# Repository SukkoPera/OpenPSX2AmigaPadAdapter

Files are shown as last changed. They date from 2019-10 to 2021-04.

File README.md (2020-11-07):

# OpenPSX2AmigaPadAdapter
OpenPSX2AmigaPadAdapter is an Open Hardware adapter that allows using a Sony PlayStation controller on Commodore computers, including the Commodore 64, Amiga and CD<sup>32</sup>.

Board

## Summary
The Commodore Amiga CD<sup>32</sup> came with cumbersome and fragile controllers, most of which did not survive the challenge of time. While many third-party replacements have surfaced in the meantime, most of them are not as solid and comfortable as the ubiquitous Sony PlayStation controllers. These have more than enough buttons, are cheap and most people are familiar with them, as the same basic design has been around for nearly 25 years. This means they would be a very good replacement, if they just didn't use a different connector and communication protocol.

OpenPSX2AmigaPadAdapter is a simple [Arduino](https://www.arduino.cc)-based board that adapts the connector and translates the protocol, allowing the use of many PlayStation controllers on Commodore computers. It can either behave as a simple 1/2-button Atari-style joystick or as a full-fledged 7-button CD<sup>32</sup> gamepad. It can also appear as an Amiga mouse.

## Operating Modes
The adapter has two leds:
- LD1 lights up steadily when a supported controller is plugged in. It blinks when no controller - or an unsupported one - is connected.
- LD2 indicates the current operating mode, to be interpreted as follows.

### Two-Button Joystick Mode
When the adapter is powered on, it defaults to Atari-style Two-Button Mode, which is indicated by LD2 being off.

This mode has been throughly tested on several Amiga models, but it **should** work wherever an Atari-style joystick is supported, including the Commodore VIC-20, Commodore 16 (through an [adapter](https://github.com/SukkoPera/OpenC16JoyAdapter)), Commodore 64, etc. See [below](#computers-and-consoles) for a compatibility table.

While in this mode, the adapter supports different button mappings, which have been carefully designed and tailored to different game genres. The mappings can be switched by pressing <kbd>Select</kbd> in combination with other buttons. LD2 will blink quickly a few times to indicate what mapping has been activated.

#### Standard Mapping: <kbd>Select</kbd> + <kbd>&square;</kbd>
Standard Mapping is the simplest mapping possible: both the D-Pad and Left Analog work as direction buttons. <kbd>&square;</kbd> is <kbd>B1</kbd> and <kbd>&cross;</kbd> is <kbd>B2</kbd>. This is the default mapping as it should be usable just about in every game out there. It might not be the most natural these days, but it's the way the game was meant to be played by the developers, thus it should never fail you.

Note that very few games were originally made to take advantage of two buttons, as even fewer controllers had that many (!) those days. [Here is a list](http://eab.abime.net/showthread.php?t=57540) of Amiga games that somehow support two buttons, if it can be any useful.

LD2 will blink once when this mapping is activated.

#### Racing Mapping 1: <kbd>Select</kbd> + <kbd>&triangle;</kbd>
Racing Mapping 1 is useful for all those racing games that use <kbd>&uarr;</kbd> to accelerate and <kbd>&darr;</kbd> to brake. These have been mapped to <kbd>&square;</kbd> and <kbd>&cross;</kbd>, respectively, which should make them much more natural to play. When accelerating and braking at the same time, braking wins. Left Analog can be used to steer, but its vertical axis is ignored, to avoid accidental accelerating/braking. The D-Pad is fully functional and is handy when moving through menus. <kbd>B1</kbd> and <kbd>B2</kbd> can be found on <kbd>&triangle;</kbd> and <kbd>&cir;</kbd>.

This mode is probably best suited to games that do not involve shifting gears, as downshifting is usually performed through <kbd>&darr;</kbd> + <kbd>B1</kbd> which is pretty hard to achieve (<kbd>&triangle;</kbd> + <kbd>&cross;</kbd>).

LD2 will blink twice when this mapping is activated.

#### Racing Mapping 2: <kbd>Select</kbd> + <kbd>&cir;</kbd>
Racing Mapping 2 is an alternative mapping for racing games that was inspired by GTA V. It lets you use <kbd>R2</kbd> (or <kbd>R1</kbd>) to accelerate and <kbd>L2</kbd> (or <kbd>L1</kbd>) to brake (which means they map to <kbd>&uarr;</kbd> and <kbd>&darr;</kbd>, respectively). <kbd>B1</kbd> is mapped to its natural <kbd>&square;</kbd> position. Steering and the D-Pad work as in Racing Mode 1.

Accidentally, this control scheme was found out to be very comfortable with games that use <kbd>B1</kbd> to accelerate and <kbd>&uarr;</kbd> and <kbd>&darr;</kbd> to shift gears. Since <kbd>&darr;</kbd> is probably used for braking as well, it has also been mapped to <kbd>&cross;</kbd>, while <kbd>B2</kbd> has been moved to <kbd>&triangle;</kbd>.

LD2 will blink three times when this mapping is activated.

#### Platform Mapping: <kbd>Select</kbd> + <kbd>&cross;</kbd>
Platform Mapping is very similar to Standard Mapping, it just makes jumping way easier on a joypad and more natural to all the Mario players out there, by replicating <kbd>&uarr;</kbd> on <kbd>&cross;</kbd>. Consequently, <kbd>B2</kbd> has been moved to <kbd>&triangle;</kbd>.

LD2 will blink four times when this mapping is activated.

#### Custom Mappings: <kbd>Select</kbd> + <kbd>R1</kbd>/<kbd>R2</kbd>/<kbd>L1</kbd>/<kbd>L2</kbd>
What if the built-in mappings are not enough? OpenPSX2AmigaPadAdapter allows you to make your own! And you can have up to four different ones, which are stored internally so that they can be recalled at any time. By default they behave similarly to the Standard Mapping, but they can be customized so that any button produces either the press of a single button or even of a button combo!

The programming procedure is as follows:

1. Press and hold <kbd>Select</kbd>, then press and hold one of <kbd>R1</kbd>/<kbd>R2</kbd>/<kbd>L1</kbd>/<kbd>L2</kbd> until LD2 starts blinking, finally release both buttons. You are now in Programming Mode.
2. Press the button you want to configure. LD2 will flash quickly a few times.
3. Press and hold the single button or button combo you want to be assigned to the button you pressed before. At this stage the D-Pad directions have their obvious meaning, while <kbd>&square;</kbd> represents <kbd>B1</kbd> and <kbd>&cross;</kbd> represents <kbd>B2</kbd>. LD2 will again flash quickly a few times.
4. Release the button or combo you were holding.
5. Repeat steps 2-4 for every button you want to customize.
6. When you are done, press <kbd>Select</kbd> to store the mapping and leave Programming Mode. LD2 will stop blinking and you will be back to Two-Button Joystick Mode.

Note that a mapping you have just programmed is not activated automatically, so you will have to press <kbd>Select</kbd> and one of <kbd>R1</kbd>/<kbd>R2</kbd>/<kbd>L1</kbd>/<kbd>L2</kbd> (and release them quickly) to switch to it.

The Custom Mappings **cannot** be configured so that <kbd>&darr;</kbd> overrides <kbd>&uarr;</kbd> or so that the vertical axis of Left Analog is ignored, still they might be useful here and there. For instance, having <kbd>B1</kbd> + <kbd>&uarr;</kbd> on <kbd>&cross;</kbd> and <kbd>B1</kbd> + <kbd>&darr;</kbd> on <kbd>&triangle;</kbd> makes the Amiga version of *Golden Axe* much more playable.

#### Commodore 64 Mode
Button 2 on Commodore 64 usually behaves in the opposite way at the electrical level, with respect to the other buttons. So a tweak can be enabled to invert the behaviour of button 2, use it if you find that your game of choice always sees it pressed or if it triggers on release rather than on press.

Just hold <kbd>Select</kbd> and press <kbd>Start</kbd> briefly. LD2 will flash once when this tweak is enabled and twice when it is disabled.

### Mouse Mode
Whenever the right analog stick is moved, the adapter switches to Amiga Mouse Mode. In this mode, the right stick emulates the movements of a mouse. Movement speed is somewhat proportional to how far the stick is moved.

This mode can be useful as an emergency mouse, and it will be particularly handy if you have the adapter connected to port 1 of an Amiga computer and you need to use a mouse for short while (maybe to do some settings in a cracktro). Instead of unplugging the adapter, plugging in a mouse, and then the adapter again, you can take advantage of this feature.

Mouse mode is indicated by LD2 blinking. Press any direction on the D-Pad to go back to Joystick or CD32 Mode.

### CD<sup>32</sup> Controller Mode
When the adapter is connected to a CD<sup>32</sup> console, it will automatically switch into this mode, which will emulate all 7 buttons of the original CD<sup>32</sup> controller. LD2 will light up steadily.

By default, buttons are mapped as follows:
- <kbd>&square;</kbd>: Red
- <kbd>&cross;</kbd>: Blue
- <kbd>&cir;</kbd>: Yellow
- <kbd>&triangle;</kbd>: Green
- <kbd>L1</kbd>/<kbd>L2</kbd>/<kbd>L3</kbd>: L
- <kbd>R1</kbd>/<kbd>R2</kbd>/<kbd>R3</kbd>: R
- <kbd>Start</kbd>: Start/Pause

If you press <kbd>Select</kbd>, the 4 main buttons get "rotated":
- <kbd>&cross;</kbd>: Red
- <kbd>&cir;</kbd>: Blue
- <kbd>&triangle;</kbd>: Yellow
- <kbd>&square;</kbd>: Green

Both the D-Pad and Left Analog always work as direction buttons.

## Components and Assembly
The board is basically a customized Arduino Uno, this means it was designed to work with an ATmega328P microcontroller, but you can also use ATmega88/A/P/PA or ATmega168/P microcontrollers, as they are pin-compatible and slightly cheaper. The A/P/PA suffixes usually identify somewhat minor chip revisions, the board should work with all of them. If you can, use P or PA versions, which consume less power. Note that at the moment the firmware uses 99% of the flash space available on an ATmega88 and any possible future improvements and/or new features are likely to overflow that, so you'd better use an ATmega168 at least.

A noteworthy exception to this rule is the ATmega328P**B**, which is NOT 100% pin-compatible with the 328P. Nevertheless, it MIGHT just work as well. It might also destroy whatever you connect the adapter to, so do it **at your own risk**.

You are recommended to solder the microcontroller first. The TQFP-32 package is easier to solder than it looks, watch some videos on YouTube and develop your own technique. Just make sure to orient it correctly.

Solder the oscillator then. You can either use a through-hole crystal with its caps (these will depend on the crystal, but usually 18-22pF are a good bet) or a 3-pin resonator. Whichever you choose, it shall have a frequency of 16 MHz. If you choose the crystal, you might want to put some insulation tape under it to avoid it touching the pads for the resonator.

Solder all the remaining parts in the order you prefer, just keep the controller connectors last.

Note that the PlayStation controller is powered at 3.3V and the interface signals use the same voltage. Due to the particular circuit used for level shifting (the microcontroller works at 5V), the MOSFETs [should really be BSS138](https://electronics.stackexchange.com/questions/367052/replace-bss138-with-ao3400a-in-level-shifter-circuit).

The PlayStation controller connector can be found from many Chinese sellers as a spare part. Get one with 90° pins, otherwise the adapter will be pretty awkward to use. The pins will be pretty short, but you should manage to solder it in place. Make sure it sits level on the board, otherwise it might not fit in the [3D-printable case](#enclosure), which you are recommended to use in order to make the adapter more mechanically solid. In alternative, some hot glue behind the connector (where the pins are) seems to do the same job, but it won't look as pretty.

**Hint:** If you don't have the PCB, you can build a full adapter with an Arduino Uno/Nano/Whatever board. This is not supported though, so you are on your own, but all the information you need is in the schematics or in the firmware code :).

## Firmware
Before you can use the adapter, you will need to load some firmware (i.e.: an Arduino sketch) on it. This can be found under the [firmware](https://github.com/SukkoPera/OpenPSX2AmigaPadAdapter/tree/master/firmware) directory, along with instructions.

## Compatibility
### Computers and Consoles
|System |Compatible |Notes |
|---|---|---|
|Commodore Amiga (All models) |Yes |Tested on A500+ and A1200 (1.D3), it is expected to be compatible with all models in both 2- and 7-button Joystick modes and in Mouse mode. |
|Commodore Amiga CD<sup>32</sup>  |Yes |Both 2- and 7-button Joystick modes and Mouse mode. Games not using `lowlevel.library` might be a bit of hit-and-miss, please report any misbehaviours. |
|Commodore CDTV |Maybe|**Not tested yet**, but expected to work in 2-button Joystick mode and Mouse mode through a connector adapter. |
|Commodore 64 |Yes |Tested in 2-button Joystick mode, but second button untested. Mouse mode might damage CIA chips though, be careful not to turn it on! |
|Commodore 16 |Maybe|**Not tested yet**, but expected to work in 2-button Joystick mode through [OpenC16JoyAdapter](https://github.com/SukkoPera/OpenC16JoyAdapter). C16 only supports Button 1 though. |
|Commodore VIC-20 |Maybe|**Not tested yet**, but expected to work in 2-button Joystick mode. Be careful with Mouse mode. |
|Sega Master System |No |Would probably work in 2-button Joystick mode if power was routed from pin 5 on the SMS controller port to pin 7 of the adapter. |
|Sega Mega Drive/Genesis |No |Would probably work as an SMS controller with the same mod as above. Some more pin rerouting AND a custom firmware could make it appear as a Mega Drive 6-button controller. |
|MSX |No |Would probably work in 2-button Joystick mode by swapping a few pins on the controller port. |

### Controllers
The latest versions of the OpenPSX2AmigaPadAdapter firmware use [PsxNewLib](https://github.com/SukkoPera/PsxNewLib) to read the PlayStation controller. This makes it compatible with (almost) all controllers.

Please refer to the [PsxNewLib Compatibility List](https://github.com/SukkoPera/PsxNewLib#compatibility-list) for details.

## Current Consumption
Following are the results of some rough measurements:
- An ATmega88PA-based OpenPSX2AmigaPadAdapter with an original Sony Dual Shock/Dual Shock 2 controller connected draws about 20 mA.
- Consumption rises to 25 mA with the dongle of my EastVita wireless controller, when the controller is connected. It peaks to 35 mA while it is searching for the controller.
- Using an ATmega328P bumps all consumptions by 5 mA.

This means that the current absorbed by the adapter is "reasonable" and that it should be safe to use in all cases. It is well below the 100 mA maximum available from any Amiga controller ports, for instance.

## Enclosure
Three different 3D-printable enclosures are currently available for this board:
- The [first](https://github.com/SukkoPera/OpenPSX2AmigaPadAdapter/tree/master/enclosure) one was kindly contributed by Petros Kokotis and needs screws for assembly.
- A [second one](https://www.thingiverse.com/thing:4620027) was designed by Lemaru and uses a snap-in design. It also has holes for the LEDs.
- [Another one](https://github.com/SukkoPera/OpenPSX2AmigaPadAdapter/tree/master/enclosure/cd32) was made by Gary Ogden and is better suited for use with the CD<sup>32</sup>, as it has some kind of bottom support.

My gratitude goes to all the three guys for their great work and support!

### Releases
If you want to get this board produced, you are recommended to get [the latest release](https://github.com/SukkoPera/OpenPSX2AmigaPadAdapter/releases) rather than the current git version, as the latter might be under development and is not guaranteed to be working.

Every release is accompanied by its Bill Of Materials (BOM) file and any relevant notes about it, which you are recommended to read carefully.

## License
The OpenPSX2AmigaPadAdapter documentation, including the design itself, is copyright &copy; SukkoPera 2019-2020.

OpenPSX2AmigaPadAdapter is Open Hardware licensed under the [CERN OHL v. 1.2](http://ohwr.org/cernohl).

You may redistribute and modify this documentation under the terms of the CERN OHL v.1.2. This documentation is distributed *as is* and WITHOUT ANY EXPRESS OR IMPLIED WARRANTIES whatsoever with respect to its functionality, operability or use, including, without limitation, any implied warranties OF MERCHANTABILITY, SATISFACTORY QUALITY, FITNESS FOR A PARTICULAR PURPOSE or infringement. We expressly disclaim any liability whatsoever for any direct, indirect, consequential, incidental or special damages, including, without limitation, lost revenues, lost profits, losses resulting from business interruption or loss of data, regardless of the form of action or legal theory under which the liability may be asserted, even if advised of the possibility or likelihood of such damages.

A copy of the full license is included in file [LICENSE.pdf](LICENSE.pdf), please refer to it for applicable conditions. In order to properly deal with its terms, please see file [LICENSE_HOWTO.pdf](LICENSE_HOWTO.pdf).

The contact points for information about manufactured Products (see section 4.2) are listed in file [PRODUCT.md](PRODUCT.md).

Any modifications made by Licensees (see section 3.4.b) shall be recorded in file [CHANGES.md](CHANGES.md).

The Documentation Location of the original project is https://github.com/SukkoPera/OpenPSX2AmigaPadAdapter/.

## Support the Project
Since the project is open you are free to get the PCBs made by your preferred manufacturer, however in case you want to support the development, you can order them from PCBWay through this link:

PCB from PCBWay (https://www.pcbway.com/project/shareproject/OpenPSX2AmigaPadAdapter_V3.html)

You get my gratitude and cheap, professionally-made and good quality PCBs, I get some credit that will help with this and [other projects](https://www.pcbway.com/project/member/shareproject/?bmbid=41100). You won't even have to worry about the various PCB options, it's all pre-configured for you!

Also, if you still have to register to that site, [you can use this link](https://www.pcbway.com/setinvite.aspx?inviteid=41100) to get some bonus initial credit (and yield me some more).

Again, if you want to use another manufacturer, feel free to, don't feel obligated :). But then you can buy me a coffee if you want:

<a href='https://ko-fi.com/L3L0U18L' target='_blank'>Buy Me a Coffee at ko-fi.com</a>

### Get Help
If you need help or have questions, you can join [the official Telegram group](https://t.me/joinchat/HUHdWBC9J9JnYIrvTYfZmg).

### Thanks
- Gerd Kautzmann for information about the [CD32 controller protocol](http://gerdkautzmann.de/cd32gamepad/cd32gamepad.html)
- CuriousInventor for informtation about the [PlayStation controller protocol](http://store.curiousinventor.com/guides/PS2)
- majinga/screwbreaker for testing and bugfixes
- Petros Kokotis, Lemaru and Gary Ogden for the 3D-printable enclosures
- Sarang Dumbre for the [3D model of the PlayStation connector](https://grabcad.com/library/ps-connector-female-1)

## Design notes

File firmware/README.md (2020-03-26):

# OpenPSX2AmigaPadAdapter Firmware

This is the firmware for the OpenPSX2AmigaPadAdapter project.

It it based on the [Arduino](https://www.arduino.cc) platform, since the OpenPSX2AmigaPadAdapter PCB is basically a customized *Arduino Uno* board. Hence you will need [the Arduino software](https://www.arduino.cc/en/Main/Software) to build and flash it to the board, so download and install it. Version 1.8.12 is the latest at the time of writing, and is recommended, although any later version should work as well.

## Core
The OpenPSX2AmigaPadAdapter firmware was tested using the default Arduino core on ATmega328P microcontrollers. You can also use ATmega88/A/P/PA or ATmega168/P microcontrollers (or even ATmega328P**B** at your risk), they are pin-compatible and slightly cheaper: in this case you will need [MiniCore](https://github.com/MCUdude/MiniCore).

## Libraries
You will need to install the following libraries:
- [PsxNewLib](https://github.com/SukkoPera/PsxNewLib): This library is used to read the PlayStation controller, you can also install it from the *Library Manager*, version 0.2.0 or later is required.
- [DigitalIO](https://github.com/SukkoPera/DigitalIO): You need this fork if your board has an ATmega88/A/P/PA or 328P**B** microcontroller, otherwise you can also use [the original version](https://github.com/greiman/DigitalIO).

If you need to install a library manually, just download the ZIP files and unpack them under ```libraries``` into your sketches directory. Please refer to the [Arduino documentation](https://www.arduino.cc/en/Guide/Libraries#toc5) for more information.

## Bootloader
You can either use a bootloader or not. There's not much difference from the functional point of view, as you will need some specialized hardware anyway:
- If you don't want to use a bootloader, you will need an AVR I(C)SP programmer every time you want to update the firmware. There are cheap clones everywhere, just look for *usbasp* or *tinyisp*.
- If you want to use a bootloader, you will still need an AVR programmer to flash the bootloader (and set the fuses) the first time, unless someone else does it for you. From then on you can just use a USB to Serial adapter. These are cheap too, just search for them. Not that useful unless you want to do some development/debugging, anyway.
- If you want to help with the debugging, you will need the USB to Serial adapter, so the only bonus in using a bootloader is that you can debug and reflash using it alone.
- Note that you can use an Arduino Uno (or similar) board as an AVR ISP programmer, if you already have one: follow [these instructions](https://www.arduino.cc/en/Tutorial/ArduinoISP).

If you go for the bootloader, you can either use the stock Arduino/MiniCore ones or have a look at the [bootloaders](https://github.com/SukkoPera/OpenPSX2AmigaPadAdapter/tree/master/firmware/bootloaders) directory, where you will find some versions of Optiboot that have been customized to flash LD2 when they startup (since there is no led connected to pin 13 as on most Arduino boards). Each of them is accompanied by the command line it was built with and by an ```avrdude``` command that can be used to flash it to the board without using the Arduino software.

## Fuses
Even if you don't want to use a bootloader, **you will need to burn it once in order to set some fuses** that are internal to the microcontroller to the right values. Then, if you don't want to use a bootloader, just pretend it never happened.

This is necessary because the Arduino software has no option dedicated to setting the fuses, but only does so contextually with burning the bootloader. In alternative, the ```bootloaders``` directory contains commands to set the fuses without using the Arduino software.

### ATmega328/P
Make sure that *Board* is set to *Arduino/Genuino Uno* under the *Tools* menu and select *Burn Bootloader*.

Note that this will set the fuses so that the board actually expects a bootloader to be installed, but programs seem to run correctly anyway if you flash them later through a programmer. You will lose 256 bytes of flash but it won't be a problem in this case, since this firmware is much smaller. To fix this properly you will need to set the fuses manually and use value ```0xDF``` for the High fuse.

### Atmega88/A/P/PA or ATmega328PB
Select the correct microcontroller type under *Tools* -> *Board* and *Variant* and set the other options in the same menu to the following values:
- Clock: *16 MHz external*
- BOD: *2.7V*
- Bootloader: *Yes* or *No* at your choice (Use the *UART0* option if applicable)

Finally select *Burn Bootloader*.

## Compiling and Flashing
1. Open the Arduino software
2. From the *File* menu select *Open* and browse to the ```OpenPSX2AmigaPadAdapter``` directory.
3. Select the correct *Board* and *Variant* under the *Tools* menu.
4. If using MiniCore, set the following values under the *Tools* menu:
   - Clock: *16 MHz external*
   - Compiler LTO: *Enabled*
5. If using the bootloader, connect the board through a Serial to USB adapter (It shall connect to the *FTDI* header on the board), make sure the correct serial port is selected in the *Tools* menu, then click on the *Upload* button (Second from left).
6. Otherwise, connect the board through an AVR programmer (using the the *ICSP* header on the board) and use the *Upload Using Programmer* menu option (Or hold <kbd>Shift</kbd> and click on the *Upload* button).

## Pin Mapping
Pins of the DB-9 connector are connected as follows on the OpenPSX2AmigaPadAdapter PCB:

|Pin#|Joystick  |CD32 |Mouse |Arduino Pin#|Arduino Pin Mode (Joystick Mode)|Arduino Pin Mode (CD32 Mode)|Arduino Pin Mode (Mouse Mode)|
|----|---|---|---|---|---|---|---|
|1 |Up |Up |V-pulse |4 |INPUT (HIGH)/OUTPUT (LOW) |INPUT (HIGH)/OUTPUT (LOW) |OUTPUT |
|2 |Down |Down |H-pulse |5 |INPUT (HIGH)/OUTPUT (LOW) |INPUT (HIGH)/OUTPUT (LOW) |OUTPUT |
|3 |Left |Left |VQ-pulse |6 |INPUT (HIGH)/OUTPUT (LOW) |INPUT (HIGH)/OUTPUT (LOW) |OUTPUT |
|4 |Right |Right |HQ-pulse |7 |INPUT (HIGH)/OUTPUT (LOW) |INPUT (HIGH)/OUTPUT (LOW) |OUTPUT |
|5 |(Button 3)|Load/Shift |MMB |2 (INT0) |INPUT |INPUT |INPUT |
|6 |Button 1  |SR Clock |LMB |3 (INT1) |INPUT (HIGH)/OUTPUT (LOW) |INPUT |INPUT (HIGH)/OUTPUT (LOW) |
|7 |+5V |+5V |+5V |- |- |- |- |
|8 |GND |GND |GND |- |- |- |- |
|9 |Button 2  |SR Output  |RMB |8 |INPUT (HIGH)/OUTPUT (LOW) |OUTPUT |INPUT (HIGH)/OUTPUT (LOW) |

Notes:
- All signals are active-low.
- Direction signals are actually driven in an open-collector fashion, which means they are toggled between INPUT (to make them HIGH) and OUTPUT mode (to make them LOW).
- This way of working requires external pull-up resistors: Those for the direction pins are built-in into the computer, while those for the buttons are on the board.

## AVR I/O Control
This is just for reference, don't care about it if you don't know what it means:

|DDR \ PORT| L | H |
|---|---|---|
| L | INPUT (5V) | INPUT + PULL-UP (5V)|
| H | OUTPUT LOW (0V)| OUTPUT HIGH (5V) |

## Logic Analyzer Plugin
The [LogicAnalyzer](https://github.com/SukkoPera/OpenPSX2AmigaPadAdapter/tree/master/firmware/LogicAnalyzer) directory contains a plug-in for the [Saleae Logic](https://www.saleae.com/downloads/) software that is capable of decoding the CD<sup>32</sup> controller protocol. It is not perfect but it's usable.

Please refer to the [Saleae documentation](https://github.com/saleae/SampleAnalyzer/tree/master/docs) for information on how to build the analyzer. Note that the directory contains a submodule, be sure to check it out as well.

## Releases
Stable versions of the firmware are released as part of the whole OpenPSX2AmigaPadAdapter project. You are recommended to use the firmware accompanying the hardware version you are using, but be sure to check [the latest release](https://github.com/SukkoPera/OpenPSX2AmigaPadAdapter/releases) as I'll try to maintain backwards compatibility. The current git version is NOT recommended though, as it might be under development and is not guaranteed to be working.

Every release is accompanied by any relevant notes about it, which you are recommended to read carefully.

## License
The OpenPSX2AmigaPadAdapter firmware is Copyright &copy; 2019-2020 by SukkoPera.

This program is free software: you can redistribute it and/or modify it under the terms of the GNU General Public License as published by the Free Software Foundation, either version 3 of the License, or (at your option) any later version.

This program is distributed in the hope that it will be useful, but WITHOUT ANY WARRANTY; without even the implied warranty of MERCHANTABILITY or FITNESS FOR A PARTICULAR PURPOSE.  See the GNU General Public License for more details.

You should have received a copy of the GNU General Public License along with this program. If not, see <http://www.gnu.org/licenses/>.

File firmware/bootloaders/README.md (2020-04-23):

# OpenPSX2AmigaPadAdapter Bootloaders
Here are some [Optiboot](https://github.com/Optiboot/optiboot) binaries customized for the OpenPSX2AmigaPadAdapter PCB.

They are compiled from the unmodified sources, the only difference versus the binaries included with Arduino and MiniCore are the LED pin, which is C1 on the OpenPSX2AmigaPadAdapter PCB.

For the commands below to work, you will need to add the AVR-GCC binaries directory to the PATH, i.e.:
```
export PATH=$PATH:/opt/arduino-1.8.10/hardware/tools/avr/bin
```

Note that your path might be different from the above. ```locate avrdude``` might help you find the correct directory.

## Flashing
You can flash these binaries with the Arduino software or simply with the ```avrdude``` tool as follows:

### ATmega328/P
#### Fuses
```
avrdude -C$HOME/.arduino15/packages/arduino/tools/avrdude/6.3.0-arduino14/etc/avrdude.conf -v -patmega328p -cusbasp -Pusb -e -Ulock:w:0x3F:m -Uefuse:w:0xFD:m -Uhfuse:w:0xDE:m -Ulfuse:w:0xFF:m
```

#### Bootloader Build
```
make atmega328 LED=C1
```

#### Bootloader Flash
```
avrdude -C$HOME/.arduino15/packages/arduino/tools/avrdude/6.3.0-arduino14/etc/avrdude.conf -v -patmega328p -cusbasp -Pusb -Uflash:w:optiboot_atmega328.hex:i -Ulock:w:0x0f:m
```

### ATmega328PB (Untested + TBD)
#### Fuses
```
avrdude -C$HOME/.arduino15/packages/arduino/tools/avrdude/6.3.0-arduino14/etc/avrdude.conf -v -patmega328pb -cusbasp -Pusb -e -Ulock:w:0x3f:m -Uefuse:w:0b11110101:m -Uhfuse:w:0xd6:m -Ulfuse:w:0b11111111:m 
```

#### Bootloader Build
```
make atmega328pb LED=C1 UART=0 BAUD_RATE=115200 AVR_FREQ=16000000
```

#### Bootloader Flash
```
avrdude -C$HOME/.arduino15/packages/arduino/tools/avrdude/6.3.0-arduino14/etc/avrdude.conf -v -patmega328pb -cusbasp -Pusb -Uflash:w:optiboot_atmega328pb_UART0_115200_16000000.hex:i -Ulock:w:0x0f:m
```

### ATmega88/A:
#### Fuses
```
avrdude -C$HOME/.arduino15/packages/MiniCore/hardware/avr/2.0.3/avrdude.conf -v -patmega88 -cusbasp -Pusb -e -Ulock:w:0x3f:m -Uefuse:w:0xfc:m -Uhfuse:w:0xd7:m -Ulfuse:w:0b11110111:m
```

#### Bootloader Build:
```
make atmega88 LED=C1 BAUD_RATE=115200 AVR_FREQ=16000000
```

#### Bootloader Flash
```
avrdude -C$HOME/.arduino15/packages/MiniCore/hardware/avr/2.0.3/avrdude.conf -v -patmega88 -cusbasp -Pusb -Uflash:w:optiboot_atmega88.hex:i -Ulock:w:0x0f:m
```

#### Application
```
avrdude -C$HOME/.arduino15/packages/MiniCore/hardware/avr/2.0.3/avrdude.conf -v -V -patmega88 -carduino -P/dev/ttyUSB0 -b115200 -D -Uflash:w:OpenPSX2AmigaPadAdapter.ino.hex:i 
```

### ATmega88P/A:
#### Fuses
```
avrdude -C$HOME/.arduino15/packages/MiniCore/hardware/avr/2.0.3/avrdude.conf -v -patmega88p -cusbasp -Pusb -e -Ulock:w:0x3f:m -Uefuse:w:0xfc:m -Uhfuse:w:0xd7:m -Ulfuse:w:0b11110111:m
```

#### Bootloader Build:
```
make atmega88pa LED=C1 UART=0 BAUD_RATE=115200 AVR_FREQ=16000000
```

#### Bootloader Flash
```
avrdude -C$HOME/.arduino15/packages/MiniCore/hardware/avr/2.0.3/avrdude.conf -v -patmega88p -cusbasp -Pusb -Uflash:w:optiboot_atmega88p_UART0_115200_16000000.hex:i -Ulock:w:0x0f:m
```

#### Application
```
avrdude -C$HOME/.arduino15/packages/MiniCore/hardware/avr/2.0.3/avrdude.conf -v -V -patmega88p -carduino -P/dev/ttyUSB0 -b115200 -D -Uflash:w:OpenPSX2AmigaPadAdapter.ino.hex:i 
```

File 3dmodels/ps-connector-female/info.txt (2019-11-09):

By sarang dumbre
https://grabcad.com/library/ps-connector-female-1
License is unknown

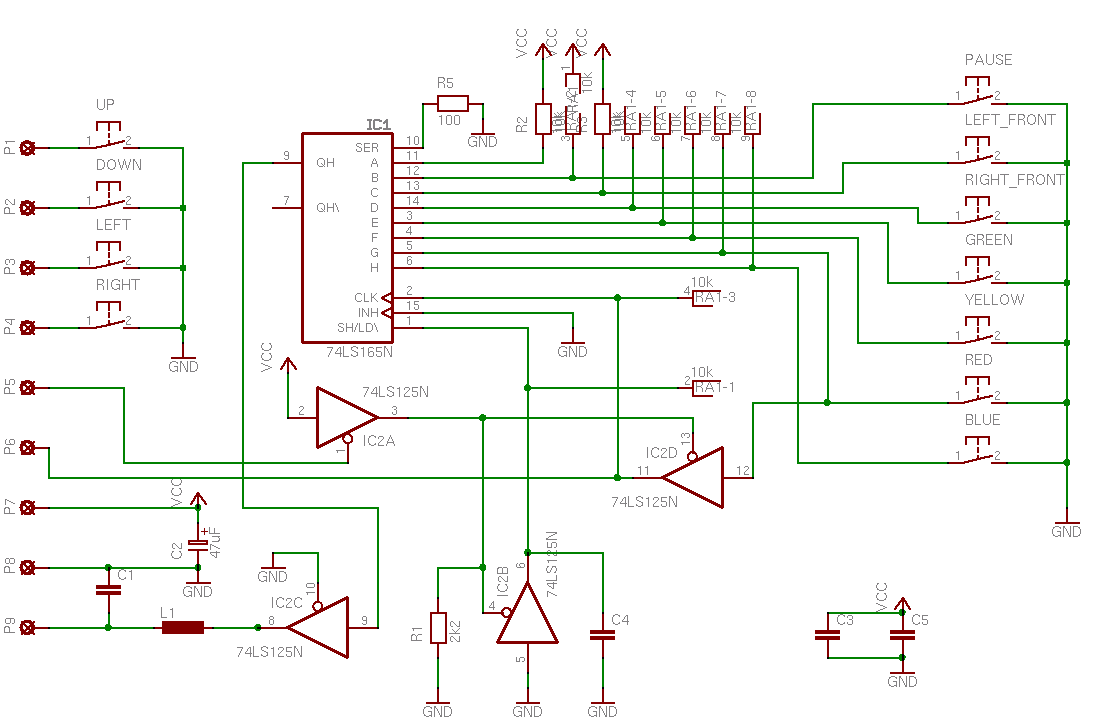
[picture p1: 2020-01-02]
doc/a100schematic.png

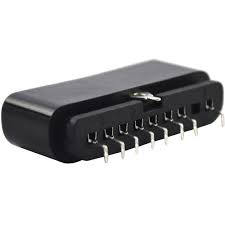
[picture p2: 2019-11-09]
3dmodels/ps-connector-female/download.jpg

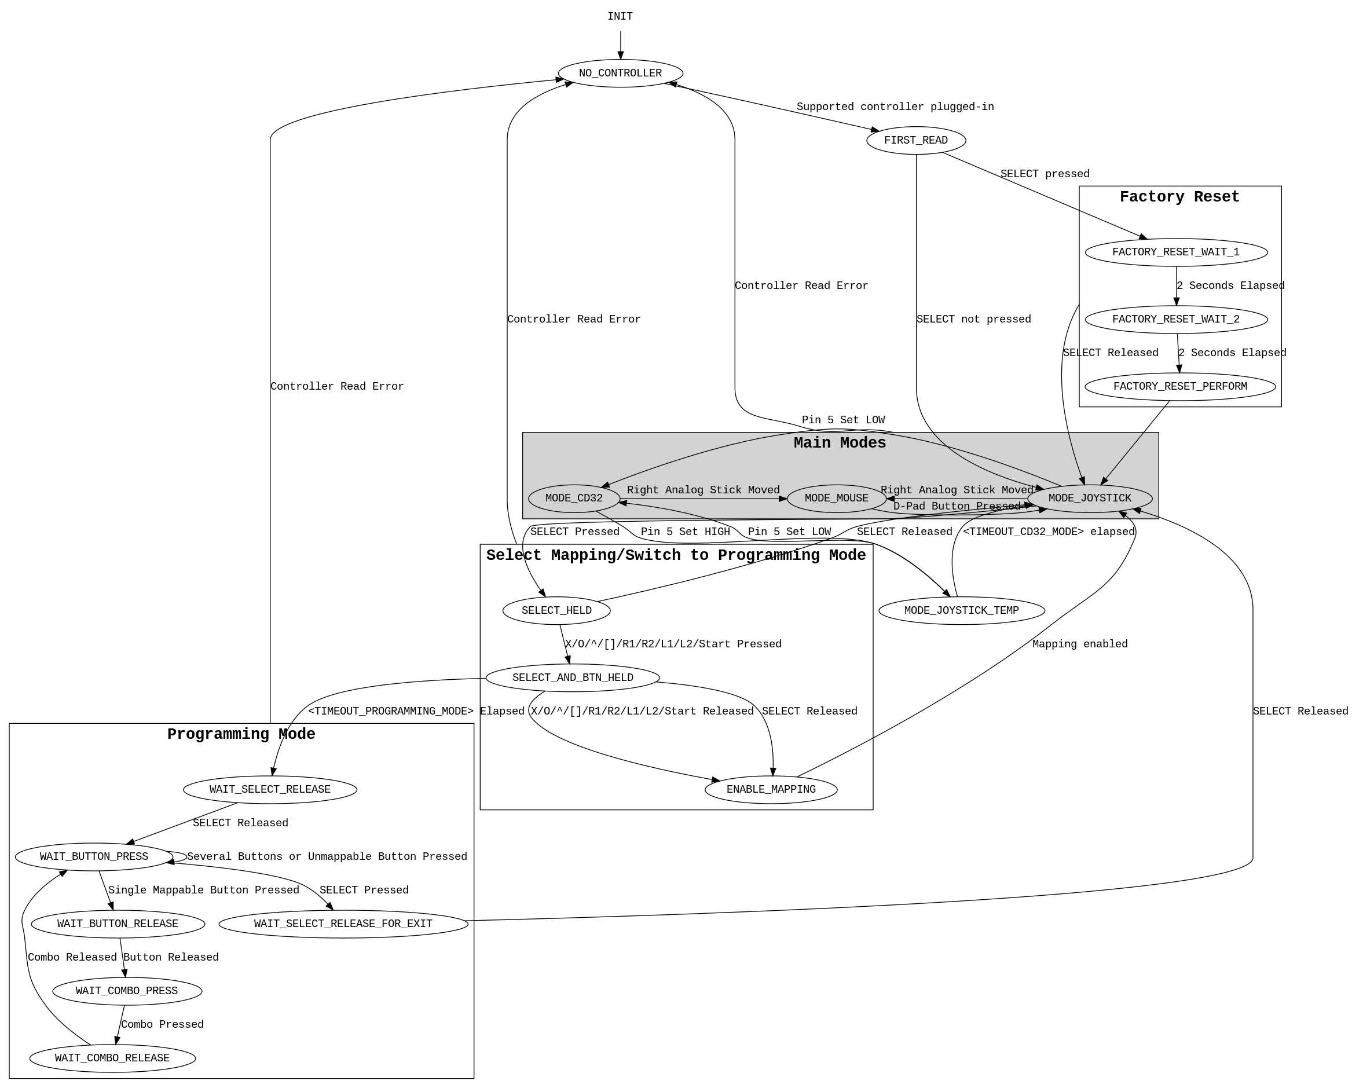
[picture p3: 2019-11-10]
firmware/statediagram.png

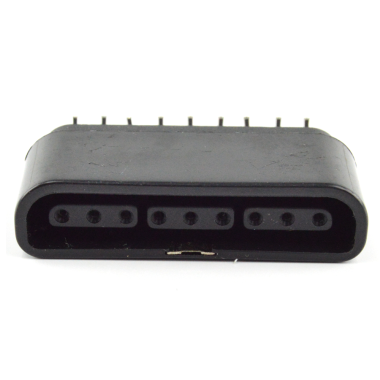
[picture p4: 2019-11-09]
3dmodels/ps-connector-female/ps2-connector.png

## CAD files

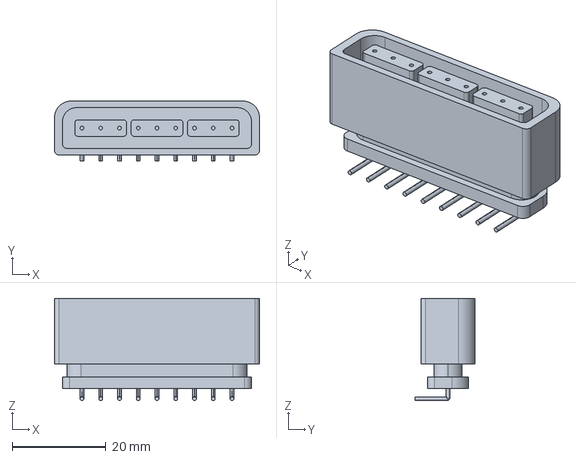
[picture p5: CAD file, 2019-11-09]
3dmodels/ps-connector-female/pritesh.stp
43.7 x 12.8 x 21.8 mm

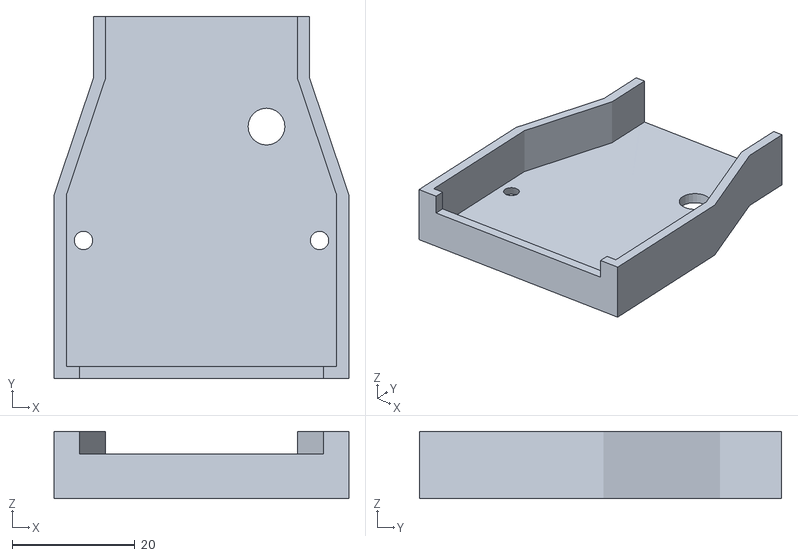
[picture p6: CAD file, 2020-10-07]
enclosure/cd32/OpenPSXAdapter-UpperShell-cd32.stl
48.0 x 59.0 x 11.0

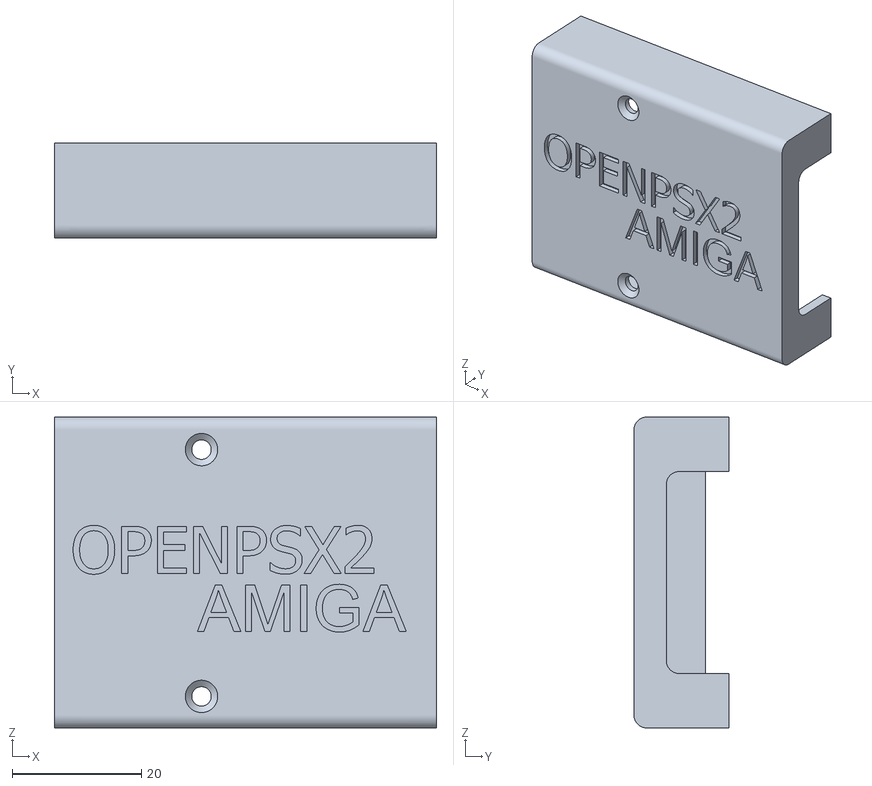
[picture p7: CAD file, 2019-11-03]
enclosure/UpperShell.stl
59.0 x 14.7 x 48.0

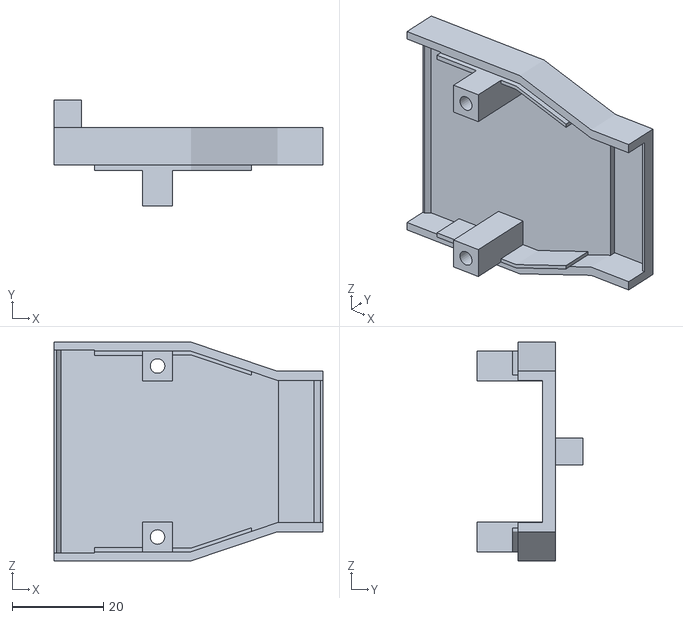
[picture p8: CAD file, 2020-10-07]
enclosure/cd32/OpenPSXAdapter-LowerShell-cd32.stl
59.0 x 23.2 x 48.0

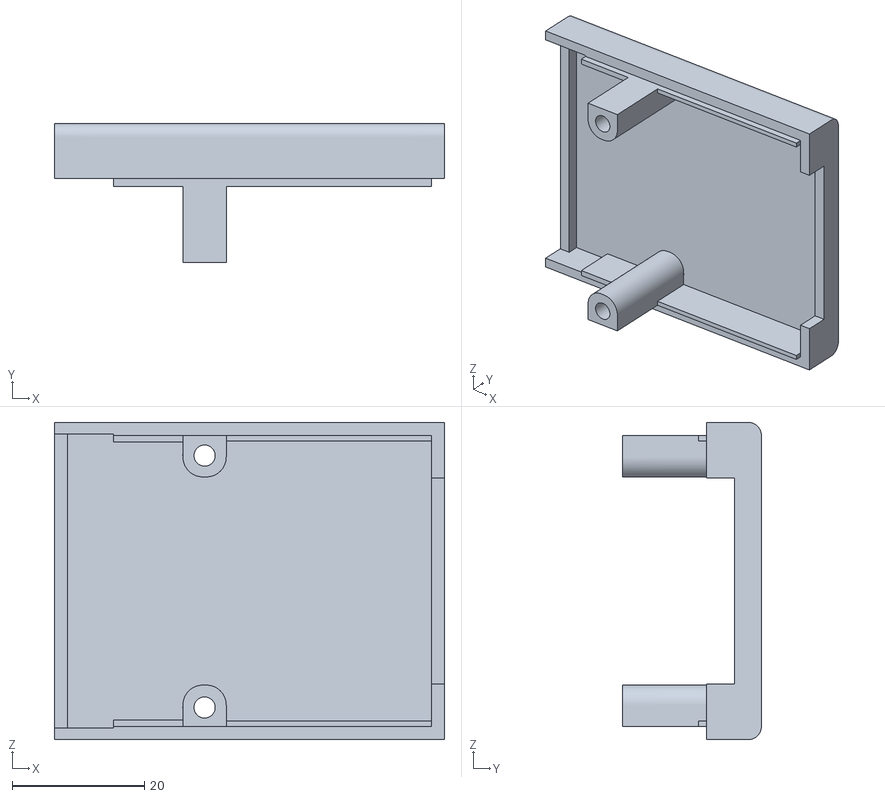
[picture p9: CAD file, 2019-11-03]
enclosure/LowerShell.stl
59.0 x 21.0 x 48.0

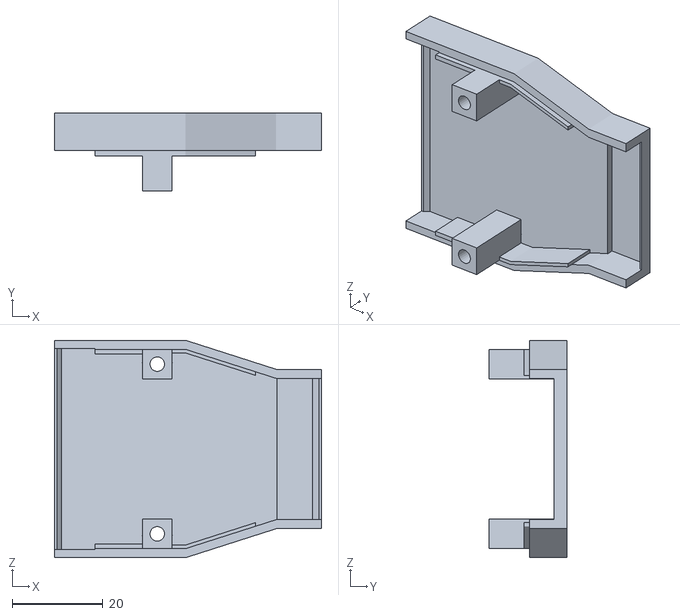
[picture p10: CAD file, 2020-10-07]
enclosure/cd32/OpenPSXAdapter-LowerShell-no_leg-cd32.stl
59.0 x 17.2 x 48.0

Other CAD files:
3dmodels/ps-connector-female/pritesh.igs
enclosure/cd32/OpenPSXAdapter-LowerShell-cd32.skp
enclosure/cd32/OpenPSXAdapter-LowerShell-no_leg-cd32.skp
enclosure/cd32/OpenPSXAdapter-UpperShell-cd32.skp

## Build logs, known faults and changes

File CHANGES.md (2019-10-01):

## CHANGES

Any modifications to the OpenPSX2AmigaPadAdapter design and documentation made by any Licensee MUST be noted in this file, as per *section 3.4.b* of the [license](LICENSE.pdf).

### (Date) - (Author)
(Description)

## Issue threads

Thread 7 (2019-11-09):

No hole for LEDs in enclosure

SukkoPera, 2019-11-09:
PCB should also be updated to allow for both SMD and THT leds.

SukkoPera, 2020-11-07:
Now we have [Lemaru's case](https://www.thingiverse.com/thing:4620027), which includes two variants allowing for LEDs to be seen. There's still no way to use THT leds but this is no longer a priority.

Thanks Lemaru :).

Closed 2020-11-07.

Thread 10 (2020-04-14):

Some questions regarding design

matsstaff, 2020-04-14:
Hi!

First off, sorry for opening an issue for something that clearly isn't an issue. Secondly, thank you so much, this seems like a very interesting project and very well documented, cleanly implemented and open one at that.

So, I'm thinking of cobbling one of these together as I've got most of the parts lying around and I do want a better controller for my Commodore machines. I just have a few questions.

Why the bidirectional level shifting for the controller? ps_data_3v3 and ps_ack_3v3 are outputs and could be directly connected to the MCU (maybe with a weak pull-up and/or a current limiting resistor). ps_cmd_3v3,  ps_clk_3v3 and ps_attn_3v3 are inputs and could use a simple voltage divider to get from 5 to 3.3v. Or am I missing something?

Why the pull-up on ami_fire? I guess there is a reason, I'm just curious as to what it is :)
Same for ami_poty (though I can guess that this has to do either with CD32 or possibly C64 button 2)?

Finally, what are the capacitors on ami_potx and ami_poty about? 820p and 220p seems small and very specific. I'm guessing again this has to do with signal conditioning for CD32 mode. How crucial are these (and their values)?

Thanks again for your very cool and very well maintained work!

Best regards from Sweden,
Mats

matsstaff, 2020-04-15:
Ok, so I've been messing about a bit and can now verify that PS_DATA and PS_ACK can be connected directly to the Arduino (but at least PS_DATA needs a pullup resistor). PS_CMD, PS_ATTN and PS_CLK can be connected by simple voltage divider.
Furthermore, using 2 signal diodes (1N4148) to drop 5v to close to 3.3v (instead of 3.3v regulator) also seems to work fine in a pinch.

SukkoPera, 2020-04-20:
Sorry for the delay, but for some reason, github didn't notify me at all that an issue had been opened. I found it by coincidence... Sigh.

No problem for opening a non-issue, it's related to the project and that's enough :).

I know the bidirectional level shifter is not strictly needed, but that was the kind of shifter I had handy when I started building the first prototype of this thing on a breadboard and I just kept using it, as it was working well. I kept thinking "I'll fix it later", but in the end... It's working very well, it's just a few additional components, a little more time in the assembly and a negligible cost increase. So why should I? There's no big saving in doing it the hackish way. Not to mention that this way I can always hack this PCB for other things (no idea what at the moment, but you never know ;)).

I am also aware that a 3v3 input to a 5v microcontroller is mostly fine, but I was just mad at all those "teachers" around saying that driving PSX controllers at 5V is 100% safe. In reaction, I wanted to do this thing as properly as I could, so I level shifted all the signals. That of course also explains why I went for 3v3 regulator. A *massive* 3v3 regulator, so that I could have lots of current. In the version currently in development (which I first tested 5 minutes ago!) I have changed it to smaller one, providing up to 100mA. Hopefully it'll still be enough.

The pull-ups on pins 6 and 9 seem to be needed by the CD32. They weren't there on the very first revision of the board and I never managed to make it work reliably until I added them in. It's weird, because many games seem to go through the whole 7-button polling routine, then just throw away what they read and re-read Buttons 1 and 2 the Atari way. See *Banshee* for instance. With the pull-ups, the lines are brought high as soon as the console releases them and everything works as it should.

The 220p and 820p caps were just carried over from the original CD32 controller design. They are probably there for EMI control or noise filtering, but they are not crucial at all. The first version didn't have these and it was no issue.

Hopefully that answers all of your questions! If you want to get the boards made, you'd rather wait a bit so that I can finish testing V4. That one also has analog joystick emulation, with which support for the Flightstick and steering wheels starts to make sense :). The tests I finished 5 minutes ago (I got the PCBs today) are promising, but the firmware needs some work. Or, if you feel lucky, you can just go with V4 right away, it's on the *devel* branch.

Or, if you want, I can send you some PCBs (all revisions!) when this Corona thing is over (May 3rd at least).

SukkoPera, 2020-04-21:
You are also allowed to criticize, it's no problem as long as it's meant to be constructive :). Sorry if I seemed annoyed, actually I wasn't, maybe I was just a bit tired. Or yeah, I was definitely annoyed by getting no notification from github, which just happened again btw.

I like discussing about my projects and design decisions. I am actually missing that, most of my projects (and they're quite a few by now) have been solo efforts, people have limited themselves to taking my work and selling it, sometimes at outrageous prices. There haven't been many cases where somebody tried to study and improve them. I don't have that much experience in electronics, so I definitely wish I had more help than I do.

I'm leaving this open, let me know how your project turns out. I like the idea of an external box where you can just plug an Arduino Pro Mini. It would be nice if someone made a PCB for that ;).

matsstaff, 2020-04-22:
I can relate. A few years ago I wrote a replacement firmware for a (then) popular cheap digital thermostat. It was really fun! Until it wasn't. I did get some useful feedback, but mainly folks didn't want to tinker, they just wanted to buy a product that works.
I was actually pretty happy that a few people picked up on buying, reflashing and reselling the thermostats, at least it got out there and I for sure was not up to doing it myself.
But it can certainly can be disheartening with no feedback, "bad" feedback (as in non-constructive) or  when people just expect you do/fix/implement things they want (without ever looking in to constraints etc). It is fine to just say "Well, the feature X that _you_ want is feasible to implement, but _I_ won't do it"

I can see that you indeed have a *lot* of projects :) Yay! It seems we even have been working on *very* similar stuff (maybe even around the same time, ~2 years ago)
https://github.com/SukkoPera/OpenAmigaDriveSwitcher
https://github.com/matsstaff/AmigaResetSwitch

I've never taken the plunge into designing and making PCB's, but I've started KiCAD many times with the intention to. Maybe some day :)

SukkoPera, 2020-04-22:
I'll be waiting patiently :).

SukkoPera, 2020-05-08:
Hey, how's your build going? :)

matsstaff, 2020-05-11:
Hi!
Sorry for the somewhat late reply. It's been a busy weekend...
I got the build done, but I've haven't had much chance to play with with it yet, as I had do stow away my C128 and get my CDTV out for another project (a wireless keyboard and mouse to CDTV converter).
I hope to get to play around with it more soon though!
Cheers!
//mats

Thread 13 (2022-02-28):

Force CD32 mode for regular Amiga

mamejay, 2022-02-28:
Hello there.  Great project.  I am just about to finish a board and just realised that you mention the controller switches to CD32 mode automatically when connected to CD32.  Is there a way to force this so can be used in a regular Amiga 500 or 1200 etc?
A lot of games are being ported over using WHDLoad and would be great to used CD32 mode controller.
Thanks and sorry if this is a silly question.

mamejay, 2022-03-01:
Cancel that.  Built the unit and found it automatically enabled CD32 support.  All good.

SukkoPera, 2022-12-12:
Yeah, it's the game that tells the joystick to switch to CD32 mode. If it does so, the adapter will just comply. This is supported on all Amiga models AFAIK (not sure about the CDTV with its odd connectors).

Closed 2022-12-12.

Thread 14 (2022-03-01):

CD32 mode constantly when connected to port 1 of C64

mamejay, 2022-03-01:
Doing more testing and found that while connected to port 1 of the C64 it is constantly in CD32 mode where LED 2 is constantly lit.
Port 2 works as expected and I can change do different modes etc.

Also in my Amiga 500 it seems to default to CD32.  Is there are way to change this to a 2 button default mode is needed?

Thanks

SukkoPera, 2022-12-12:
Grrr, I realize I missed many issues, GitHub never notified me for some reason, sorry for that.

I have noticed the C64 issue, too, it is due to pin 5 of the port being low. I will introduce a method to disable CD32 mode at startup.

It shouldn't happen on the A500 though, pin 5 should normally be high on all Amigas.

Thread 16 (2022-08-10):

Atmega88PB and Atmega328PB

mamejay, 2022-08-10:
Hey there.  I have a bunch of Atmega88PB and Atmega328PB chips available which I would like to finally use for something.
There is a bootloader for the 328PB in the github but nothing for the 88PB.  Can I just use the bootloader from Ardunio IDE?
Last thing the firmware 88p and 328p.  Can I use these files with the PB chips or do I have to recompile the binaries again?  Probably a silly question but I am not great with these things.

Thanks!

zambujal, 2022-11-18:
Sukkopera said that the 88 had lack of memory so it's impossible to fit the bootloader, you have to use an programmer for this tyoe of chips, allthough an 88p worked with lag with me...  I wonder If it was an faulty chip.

SukkoPera, 2022-12-12:
Sorry, somehow I missed this issue.

I heven't touched this thing in a while, but I think the code does no longer fit on an ATmega88... Or maybe it does by a very small margin, which basically rules out the bootloader.

The 'PB variant work mostly fine, but these models do not properly support a quartz-based clock. In my experience this means that sometimes the board will not start or it will crash if you just touch the board. You can use the Arduino bootloader anyway, in case, and since I never distributed pre-compiled binaries, you will have to compile the code yourself. Use MiniCore with these CPUs.

@zambujal's issue with the '88 was just the fuses not being set, I seem to recall we solved this elsewhere.

Hope it helps.

Closed 2022-12-12.

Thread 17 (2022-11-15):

it's not an issue just an question

zambujal, 2022-11-15:
I asked about the ressonator and the crystal... but then I read your read.me...  ;)

now I used the ATMEGA 88, there was lag... not with the 328 (I removed the 88, and soldered the 328p) not that many, but annoying. could be an malfunction chip? I wonder...

ha another cup of coffe to you.. for you to give to charity... if you want Sukkopera!
I bought 5 pcb from pcbway.... so I already give one to a friend of mine... ;) that I don't know in person... free of charge! the way this should allways be... FREE or as we portuguese say... GRATIS... is better!

zambujal, 2022-11-16:
never mind it's working without the ressonator of course and with the 2 caps

zambujal, 2022-11-16:
thank you for the project sukkopera.. it as a little lag  (0.1 sec) on the amiga 1200... going to try it on amiga cd32
...it's fine it's mostly for adventure games. ;)

SukkoPera, 2022-12-12:
Sorry, somehow I missed this issue.

I seem to recall we solved this elsewhere, the problem was just the fuses not being set, you should do so with the *Burn Booloader* command before flashing the firmware.

Thanks for your support and enthusiasm about this and my other projects :).

Closed 2022-12-12.

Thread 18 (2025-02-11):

Feels verry sluggish, fuse settings wrong?

Retrofletch, 2025-02-11:
so i built 3pcs of this and they all act the same way, feeling verry sluggish.
First of all it takes 40sec - 1min before it even comes on ( led turns on and it starts reacting to buttons )
and then in games its verry delayed, laggy. Tested on both amiga and c64 and compared with normal old joystick

i suspect that the fuses might not be getting set correctly?
I use the following commands and in this order.

Fuses :
`avrdude -C avrdude.conf -v -patmega328p -cusbasp -Pusb -e -Ulock:w:0x3F:m -Uefuse:w:0xFD:m -Uhfuse:w:0xDE:m -Ulfuse:w:0xFF:m`

Bootloader:
`avrdude -C avrdude.conf -v -patmega328p -cusbasp -Pusb -Uflash:w:optiboot_atmega328.hex:i -Ulock:w:0x0f:m`

Application:
`avrdude -C avrdude.conf -v -V -patmega328p -cusbasp -Pusb -b115200 -D -Uflash:w:OpenPSX2AmigaPadAdapter.ino.hex:i `

everything seems to go as intended except i get a error on one of the fuses, and then as you can see on last row it says fuses are not the same whatsoever. any idea?

```
avrdude: 1 bytes of efuse written
avrdude: verifying efuse memory against 0xFD:
avrdude: load data efuse data from input file 0xFD:
avrdude: input file 0xFD contains 1 bytes
avrdude: reading on-chip efuse data:

Reading | ################################################## | 100% 0.01s

avrdude: verifying ...
avrdude: verification error, first mismatch at byte 0x0000
         0x05 != 0xfd
avrdude: verification error; content mismatch

avrdude: safemode: lfuse reads as 62
avrdude: safemode: hfuse reads as D9
avrdude: safemode: efuse reads as 5
avrdude: safemode: efuse changed! Was fd, and is now 5
Would you like this fuse to be changed back? [y/n] n
avrdude: safemode: Fuses OK (E:FD, H:D9, L:62)
```

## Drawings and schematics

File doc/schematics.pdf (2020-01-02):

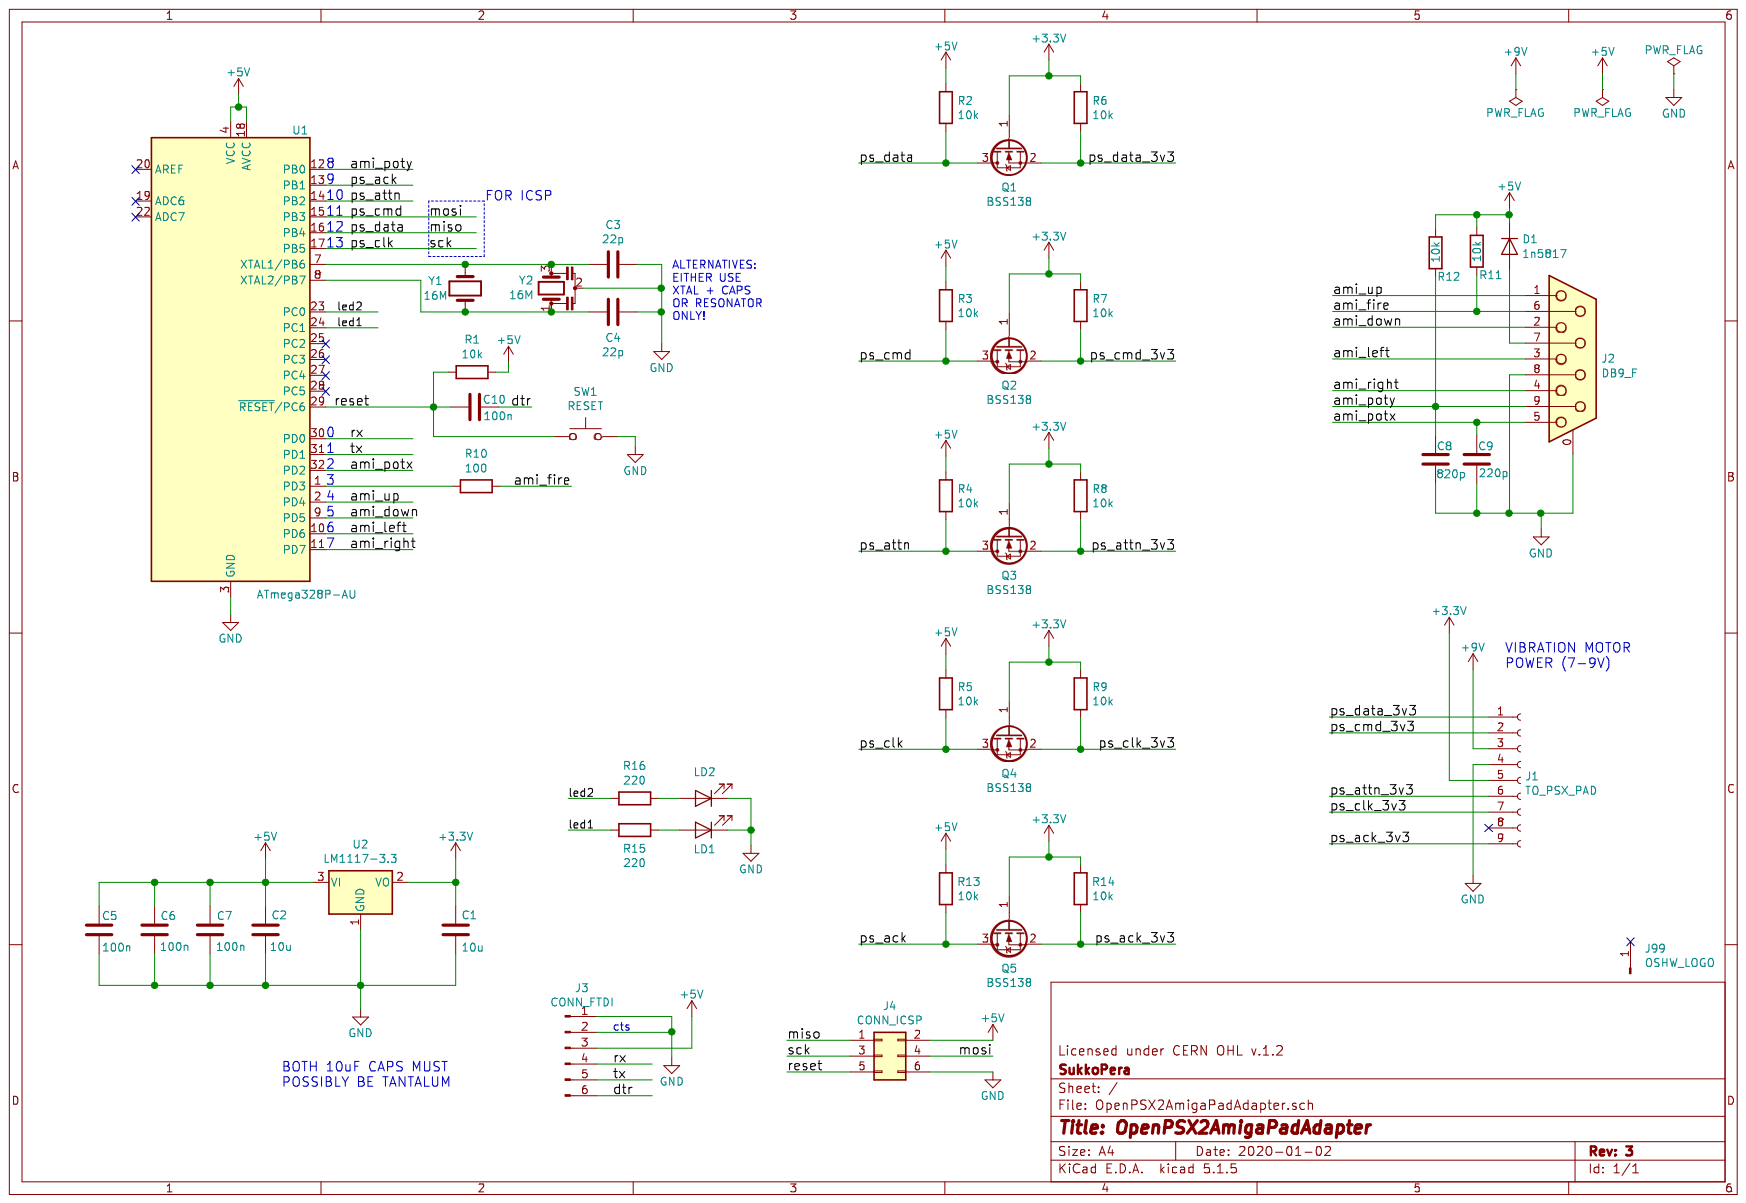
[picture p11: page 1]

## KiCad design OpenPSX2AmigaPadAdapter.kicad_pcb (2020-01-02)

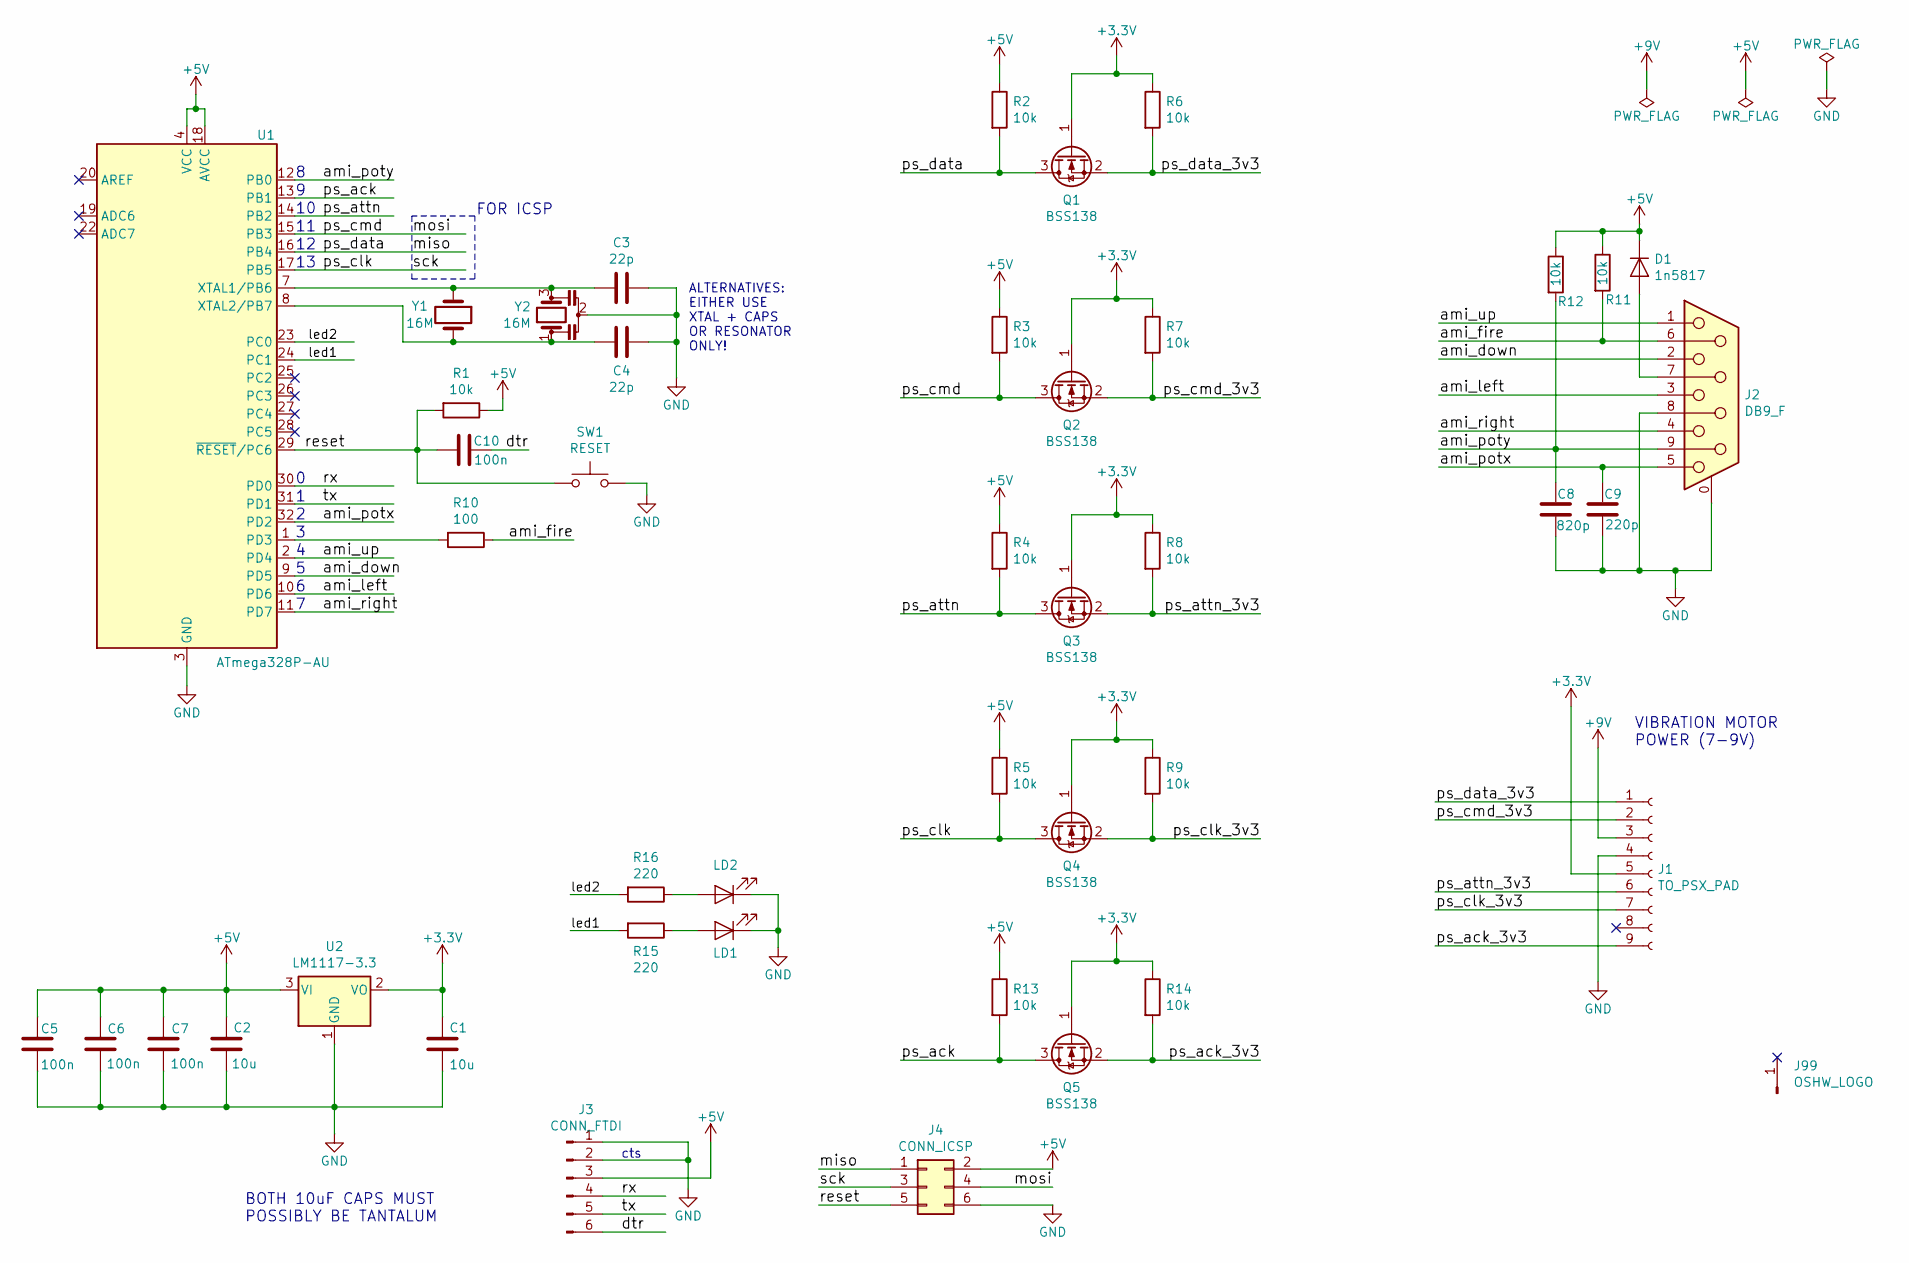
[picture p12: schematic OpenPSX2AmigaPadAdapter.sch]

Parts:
C1, C2: 10u; C_1206_3216Metric_Pad1.42x1.75mm_HandSolder
C3, C4: 22p; C_0805_2012Metric_Pad1.15x1.40mm_HandSolder
C5, C6, C7, C10: 100n; C_0805_2012Metric_Pad1.15x1.40mm_HandSolder
C8: 820p; C_0805_2012Metric_Pad1.15x1.40mm_HandSolder
C9: 220p; C_0805_2012Metric_Pad1.15x1.40mm_HandSolder
D1: 1n5817; D_SMA
J1: TO_PSX_PAD; PSX_Pad_Connector
J2: DB9_F; DB_9F
J3: CONN_FTDI; PinHeader_1x06_P2.54mm_Vertical
J4: CONN_ICSP; PinHeader_2x03_P2.54mm_Vertical
J99: OSHW_LOGO; OSHW-Logo_5.7x6mm_Copper
LD1, LD2: LED; LED_0805_2012Metric_Pad1.15x1.40mm_HandSolder
Q1, Q2, Q3, Q4, Q5: BSS138; SOT-23_Handsoldering
R1, R2, R3, R4, R5, R6, R7, R8, R9, R11, R12, R13, R14: 10k; R_0805_2012Metric_Pad1.15x1.40mm_HandSolder
R10: 100; R_0805_2012Metric_Pad1.15x1.40mm_HandSolder
R15, R16: 220; R_0805_2012Metric_Pad1.15x1.40mm_HandSolder
SW1: RESET
U1: ATmega328P-AU; TQFP-32_7x7mm_P0.8mm
U2: LM1117-3.3; SOT-223-3_TabPin2
Y1: 16M; Crystal_HC49-U_Vertical
Y2: 16M; Resonator_SMD_muRata_CSTxExxV

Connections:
+3V3: C1.2, J1.5, Q1.1 (G), Q2.1 (G), Q3.1 (G), Q4.1 (G), Q5.1 (G), R6.1, R7.1, R8.1, R9.1, R14.1, U2.2 (VO)
+5V: C2.2, C5.2, C6.2, C7.2, D1.1 (K), J3.3, J4.2, R1.1, R2.1, R3.1, R4.1, R5.1, R11.1, R12.1, R13.1, U1.4 (VCC), U1.6 (VCC), U1.18 (AVCC), U2.3 (VI)
/ami_down: J2.2, U1.9 (PD5)
/ami_fire: J2.6, R10.1, R11.2
/ami_left: J2.3, U1.10 (PD6)
/ami_potx: C9.1, J2.5, U1.32 (PD2)
/ami_poty: C8.1, J2.9, R12.2, U1.12 (PB0)
/ami_right: J2.4, U1.11 (PD7)
/ami_up: J2.1, U1.2 (PD4)
/dtr: C10.1, J3.6
/led1: R15.2, U1.24 (PC1)
/led2: R16.2, U1.23 (PC0)
/miso: J4.1, Q1.3 (D), R2.2, U1.16 (PB4)
/mosi: J4.4, Q2.3 (D), R3.2, U1.15 (PB3)
/ps_ack: Q5.3 (D), R13.2, U1.13 (PB1)
/ps_ack_3v3: J1.9, Q5.2 (S), R14.2
/ps_attn: Q3.3 (D), R4.2, U1.14 (PB2)
/ps_attn_3v3: J1.6, Q3.2 (S), R8.2
/ps_clk: J4.3, Q4.3 (D), R5.2, U1.17 (PB5)
/ps_clk_3v3: J1.7, Q4.2 (S), R9.2
/ps_cmd_3v3: J1.2, Q2.2 (S), R7.2
/ps_data_3v3: J1.1, Q1.2 (S), R6.2
/reset: C10.2, J4.5, R1.2, SW1.1, U1.29 (~RESET~/PC6)
/rx: J3.4, U1.30 (PD0)
/tx: J3.5, U1.31 (PD1)
GND: C1.1, C2.1, C3.1, C4.1, C5.1, C6.1, C7.1, C8.2, C9.2, J1.4, J2.0 (PAD), J2.8, J3.1, J3.2, J4.6, LD1.1 (K), LD2.1 (K), SW1.2, U1.3 (GND), U1.5 (GND), U1.21 (GND), U2.1 (GND), Y2.2
unnamed: C3.2, U1.7 (XTAL1/PB6), Y1.1, Y2.3
unnamed: C4.2, U1.8 (XTAL2/PB7), Y1.2, Y2.1
unnamed: D1.2 (A), J2.7
unnamed: LD1.2 (A), R15.1
unnamed: LD2.2 (A), R16.1
unnamed: R10.2, U1.1 (PD3)

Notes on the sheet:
VIBRATION MOTOR POWER (7-9V)
BOTH 10uF CAPS MUST POSSIBLY BE TANTALUM
FOR ICSP
ALTERNATIVES: EITHER USE XTAL + CAPS OR RESONATOR ONLY!
cts

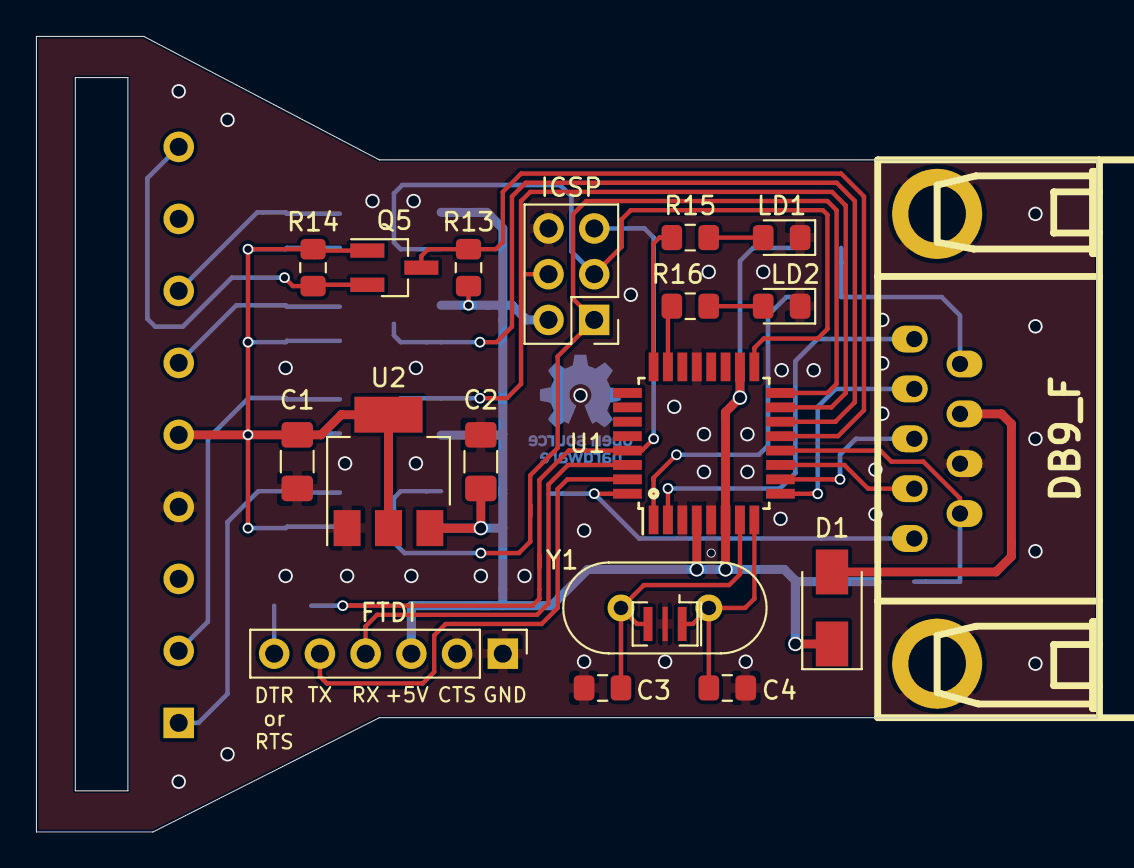
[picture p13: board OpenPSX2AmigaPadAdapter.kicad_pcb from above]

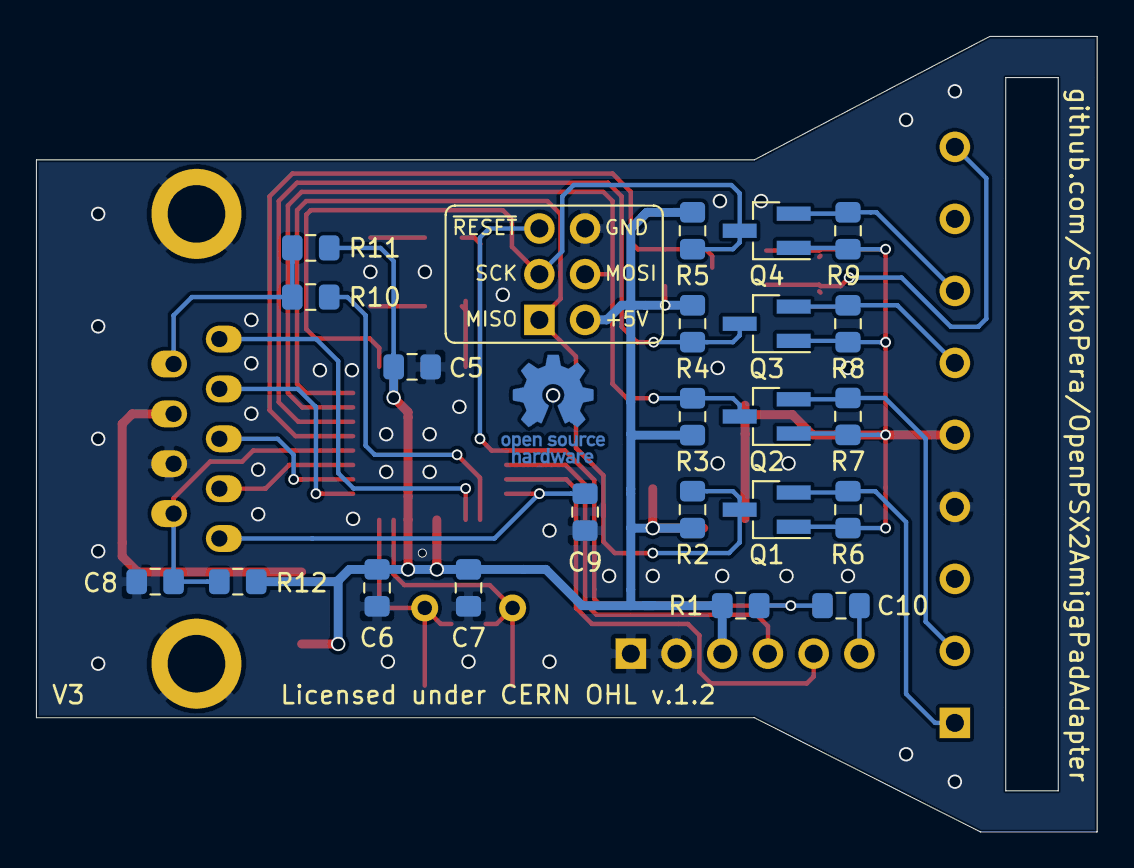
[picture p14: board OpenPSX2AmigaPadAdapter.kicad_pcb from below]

Board: 2 copper layers, 58.9 x 44.2 mm, 43 parts (23 on the bottom side), 32 nets.

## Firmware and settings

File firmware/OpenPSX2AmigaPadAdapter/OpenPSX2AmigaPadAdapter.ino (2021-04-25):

/*******************************************************************************
 * This file is part of OpenPSX2AmigaPadAdapter.                               *
 *                                                                             *
 * Copyright (C) 2019-2020 by SukkoPera <software@sukkology.net>               *
 *                                                                             *
 * OpenPSX2AmigaPadAdapter is free software: you can redistribute it and/or    *
 * modify it under the terms of the GNU General Public License as published by *
 * the Free Software Foundation, either version 3 of the License, or           *
 * (at your option) any later version.                                         *
 *                                                                             *
 * OpenPSX2AmigaPadAdapter is distributed in the hope that it will be useful,  *
 * but WITHOUT ANY WARRANTY; without even the implied warranty of              *
 * MERCHANTABILITY or FITNESS FOR A PARTICULAR PURPOSE.  See the               *
 * GNU General Public License for more details.                                *
 *                                                                             *
 * You should have received a copy of the GNU General Public License           *
 * along with OpenPSX2AmigaPadAdapter. If not, see http://www.gnu.org/licenses.*
 ******************************************************************************/
/**
 * \file OpenPSX2AmigaPadAdapter.ino
 * \author SukkoPera <software@sukkology.net>
 * \date 26 Mar 2020
 * \brief Playstation to Commodore Amiga/CD32 controller adapter
 *
 * Please refer to the GitHub page and wiki for any information:
 * https://github.com/SukkoPera/OpenPSX2AmigaPadAdapter
 */

#include <EEPROM.h>
#include <util/crc16.h>
#include <PsxNewLib.h>
#include <PsxControllerHwSpi.h>

/** \brief Enable heavy optimization
 * 
 * This enables some inline assembly code, GCC-style ISRs, etc.
 * 
 * Code has only been tested with this being enabled, so you'd better not touch
 * it.
 */
#define SUPER_OPTIMIZE

/** \brief Enable fast control of I/O pins
 *
 * This enables very fast (2 clock cycles) control of I/O pins. The DigitalIO
 * library by greiman is needed for this: https://github.com/greiman/DigitalIO.
 * 
 * This is basically mandatory for all targets currently supported, where the
 * Arduino digitalRead()/digitalWrite() functions are too slow. This define is
 * provided to make it easy to transition to faster platforms one day, should we
 * ever want to.
 */
#define ENABLE_FAST_IO

/** \def ENABLE_INSTRUMENTATION
 * 
 * \brief Enable code instrumentation
 *
 * This makes a couple of I/O pins toggle whenever ISRs are entered and is a
 * means to measure how long they take to execute fully, by using a logic
 * analyzer or oscilloscope.
 * 
 * Disabled by default.
 */
//~ #define ENABLE_INSTRUMENTATION

/** \def DISABLE_FACTORY_RESET
 *
 * \brief Disable factory reset
 * 
 * This disables the factory reset for joystick configurations. The only point
 * here is to save some flash, for ATmega88 targets. EEPROM can be cleared with
 * the \a eeprom_clear Arduino example.
 * 
 * At the moment we fit on all supported targets with this enabled, so just
 * ignore it.
 */
//~ #define DISABLE_FACTORY_RESET

//! \name OUTPUT pins, connected to Amiga port
//! @{
const byte PIN_UP = 4;    //!< Amiga Pin 1
const byte PIN_DOWN = 5;  //!< Amiga Pin 2
const byte PIN_LEFT = 6;  //!< Amiga Pin 3
const byte PIN_RIGHT = 7; //!< Amiga Pin 4
const byte PIN_BTN1 = 3;  //!< Amiga Pin 6
const byte PIN_BTN2 = 8;  //!< Amiga Pin 9
//! @}

/** \brief Controller mode input pin
 *  
 * This pin switches between Amiga (HIGH) and CD32 (LOW) mode.
 * 
 * It also triggers the loading of the button status shift register.
 */
const byte PIN_PADMODE = 2; // Amiga Pin 5

/** \brief Shift register output pin for CD32 mode
 * 
 * When in CD32 mode, button status is saved to an 8-bit register that gets
 * shifted out one bit at a time through this pin.
 */
const byte PIN_BTNREGOUT = PIN_BTN2;

/** \brief Shift register clock input pin for CD32 mode
 * 
 * The shifting is clocked by rising edges on this pin.
 */
const byte PIN_BTNREGCLK = PIN_BTN1;

/** \brief Dead zone for analog sticks
 *  
 * If the analog stick moves less than this value from the center position, it
 * is considered still.
 * 
 * \sa ANALOG_IDLE_VALUE
 */
const byte ANALOG_DEAD_ZONE = 50U;

/** \brief Controller polling frequency
 *
 * Polling the PS2 controller takes a considerable amount of time, so we cannot
 * do that all the time. Considering that an Amiga game cannot read inputs more
 * than once every frame, 60 seems a reasonable value here, taking care of both
 * PAL and NTSC machines.
 */
const byte PAD_POLLING_FREQ = 60U;

/** \brief Delay of the quadrature square waves when mouse is moving at the
 * \a slowest speed
 */
const byte MOUSE_SLOW_DELTA	= 250U;

/** \brief Delay of the quadrature square waves when mouse is moving at the
 * \a fastest speed.
 */
const byte MOUSE_FAST_DELTA = 10U;

/** \brief LED2 pin
 * 
 * Pin for led that lights up whenever the proper controller is detected.
 */
const byte PIN_LED_PAD_OK = A1;

/** \brief LED1 pin
 * 
 * Pin for led that lights up whenever the adapter is in CD32 mode.
 */
const byte PIN_LED_MODE = A0;

/** \brief Pin used for Controller Attention (ATTN)
 *
 * Pin that makes the controller pay attention to what we're saying.
 */
const byte PIN_CONTROLLER_ATTN = 10;

/** \brief CD32 mode timeout
 * 
 * Normal joystick mode will be entered if PIN_PADMODE is not toggled for this
 * amount of milliseconds.
 * 
 * Keep in mind that in normal conditions it is toggled once per frame (i.e.
 * every ~20 ms).
 */
const byte TIMEOUT_CD32_MODE = 100U;

/** \brief Programming mode timeout
 * 
 * Programming mode will be entered if SELECT + a button are held for this
 * amount of milliseconds.
 */
const unsigned long TIMEOUT_PROGRAMMING_MODE = 1000U;

/** \brief Single-button debounce time
 * 
 * A combo will be considered valid only after it has been stable for this
 * amount of milliseconds.
 * 
 * \sa debounceButtons()
 */
const unsigned long DEBOUNCE_TIME_BUTTON = 30U;

/** \brief Combo debounce time
 * 
 * A combo will be considered valid only after it has been stable for this
 * amount of milliseconds. This needs to be greater than #DEBOUNCE_TIME_BUTTON
 * to allow combos to be entered correctly, as it's hard to press several
 * buttons at exactly the same moment.
 * 
 * \sa debounceButtons()
 */
const unsigned long DEBOUNCE_TIME_COMBO = 150U;


/*******************************************************************************
 * DEBUGGING SUPPORT
 ******************************************************************************/

// Send debug messages to serial port
//~ #define ENABLE_SERIAL_DEBUG

// Print the controller status on serial. Useful for debugging.
//~ #define DEBUG_PAD

// Print the duration of every loop() iteration
//~ #define ENABLE_DEBUG_LOOP_DURATION


/*******************************************************************************
 * END OF SETTINGS
 ******************************************************************************/

#ifdef ENABLE_FAST_IO
#include <DigitalIO.h>		// https://github.com/greiman/DigitalIO
#else
#define fastDigitalRead(x) digitalRead(x)
#define fastDigitalWrite(x, y) digitalWrite(x, y)
#define fastPinMode(x, y) pinMode(x, y)
#endif

#ifdef ENABLE_INSTRUMENTATION
#define PIN_INTERRUPT_TIMING A2
#define PIN_CD32MODE A4
#endif

//! \name Button bits for CD32 mode
//! @{
const byte BTN_BLUE =		1U << 0U;	//!< \a Blue Button
const byte BTN_RED =		1U << 1U;	//!< \a Red Button
const byte BTN_YELLOW =		1U << 2U;	//!< \a Yellow Button
const byte BTN_GREEN =		1U << 3U;	//!< \a Green Button
const byte BTN_FRONT_R =	1U << 4U;	//!< \a Front \a Right Button
const byte BTN_FRONT_L =	1U << 5U;	//!< \a Front \a Left Button
const byte BTN_START =		1U << 6U;	//!< \a Start/Pause Button
//! @}

#define ATTR_PACKED __attribute__((packed))

/** \brief State machine states
 * 
 * Possible states for the internal state machine that drives the whole thing.
 * 
 * Note that we make this \a packed so that it fits in a single byte.
 */
enum ATTR_PACKED State {
	ST_NO_CONTROLLER,			//!< No controller connected
	ST_FIRST_READ,				//!< First time the controller is read
	
	// Main functioning modes
	ST_JOYSTICK,				//!< Two-button joystick mode
	ST_MOUSE,					//!< Mouse mode
	ST_CD32,					//!< CD32-controller mode
	ST_JOYSTICK_TEMP,			//!< Just come out of CD32 mode, will it last?
	
	// States to select mapping or go into programming mode
	ST_SELECT_HELD,				//!< Select being held
	ST_SELECT_AND_BTN_HELD,		//!< Select + mapping button being held
	ST_ENABLE_MAPPING,			//!< Select + mapping button released, enable mapping
	
	// States for programming mode
	ST_WAIT_SELECT_RELEASE,		//!< Select released, entering programming mode
	ST_WAIT_BUTTON_PRESS,		//!< Programmable button pressed
	ST_WAIT_BUTTON_RELEASE,		//!< Programmable button released
	ST_WAIT_COMBO_PRESS,		//!< Combo pressed
	ST_WAIT_COMBO_RELEASE,		//!< Combo released
	ST_WAIT_SELECT_RELEASE_FOR_EXIT,	//!< Wait for select to be released to go back to joystick mode
	
	// States for factory reset
#ifndef DISABLE_FACTORY_RESET
	ST_FACTORY_RESET_WAIT_1,
	ST_FACTORY_RESET_WAIT_2,
	ST_FACTORY_RESET_PERFORM
#endif
};

/** \brief All possible button mappings
 * 
 * This is only used for blinking the led when mapping is changed
 */
enum ATTR_PACKED JoyButtonMapping {
	JMAP_NORMAL = 1,
	JMAP_RACING1,
	JMAP_RACING2,
	JMAP_PLATFORM,
	JMAP_CUSTOM
};

/** \brief Structure representing a standard 2-button Atari-style joystick
 * 
 * This is used for gathering button presses according to different button
 * mappings.
 * 
 * True means pressed.
 * 
 * We use bitfields so that it all fits in a single byte.
 */
struct TwoButtonJoystick {
	boolean up: 1;			//!< Up/Forward direction
	boolean down: 1;		//!< Down/Backwards direction
	boolean left: 1;		//!< Left direction
	boolean right: 1;		//!< Right direction
	boolean b1: 1;			//!< Button 1
	boolean b2: 1;			//!< Button 2
};

/** \brief Map a PSX button to a two-button-joystick combo
 * 
 * There's an entry for every button, even those that cannot be mapped, for
 * future extension.
 *
 * Use #psxButtonToIndex() to convert a button to the index to use in the array.
 * 
 * \sa isButtonMappable()
 */
struct ControllerConfiguration {
	/** Two-button joystick combo to send out when the corresponding button is
	 * pressed
	 */
	TwoButtonJoystick buttonMappings[PSX_BUTTONS_NO];
};

//! \name Global variables
//! @{

//! PS2 Controller Class
PsxControllerHwSpi<PIN_CONTROLLER_ATTN> psx;

/** \brief Current state of the internal state machine
 * 
 * We start out as a simple joystick.
 * 
 * We keep this in \a GPIOR2 for faster access and slimmer code.
 * 
 * \hideinitializer
 */
volatile State *state = reinterpret_cast<volatile State *> (&GPIOR2);

/** \brief All possible controller configurations
 * 
 * Since these are activated with SELECT + a button, ideally there can be as
 * many different ones as other buttons we have (i.e.: PSX_BUTTONS_NO). In
 * practice, we will start handling only a handful.
 */
ControllerConfiguration controllerConfigs[PSX_BUTTONS_NO];

//! \brief Custom controller configuration currently selected
ControllerConfiguration *currentCustomConfig = NULL;

/** \brief Button register for CD32 mode being updated
 * 
 * This shall be updated as often as possible, and is what gets sampled when we
 * get a falling edge on #PIN_PADMODE.
 * 
 * 0 means pressed, MSB must be 1 for the ID sequence.
 * 
 * We keep this in \a GPIOR0 for faster ISR code. Note that GPIOR0 is one of the
 * lowest 64 registers on ATmega88/168/328's, thus it can be used with
 * SBI/CBI/SBIC/SBIS. I don't know if GCC takes advantage of this, but we do in
 * the \a asm_isr branch.
 * 
 * \hideinitializer
 */
volatile byte *buttonsLive = &GPIOR0;

/** \brief Button register for CD32 mode currently being shifted out
 * 
 * This is where #buttonsLive gets copied when it is sampled.
 * 
 * 0 means pressed, etc.
 * 
 * We keep this in \a GPIOR1 for faster ISR code.
 * 
 * \hideinitializer
 */
volatile byte *isrButtons = &GPIOR1;

/** \brief Joystick mapping function
 * 
 * This represents a function that should inspect the buttons currently being
 * pressed on the PSX controller and somehow map them to a #TwoButtonJoystick to
 * be sent to the DB-9 port.
 */
typedef void (*JoyMappingFunc) (TwoButtonJoystick& j);

// Default button mapping function prototype for initialization of the following
void mapJoystickNormal (TwoButtonJoystick& j);

//! \brief Joystick mapping function currently in effect
JoyMappingFunc joyMappingFunc = mapJoystickNormal;

/** \brief Commodore 64 mode
 *
 * Button 2 on the C64 is usually expected to behave differently from the other
 * buttons, so that it is HIGH when pressed and LOW when released.
 *
 * If this flag is true, we'll do exactly that.
 */
boolean c64Mode = false;

/** \brief Use alternative CD32 mapping
 * 
 * To me the Red button maps naturally to Square, Blue to Cross and so on. Some
 * people feel this way buttons are "rotated" with regard to the original CD32
 * controller, hence let's give them the possibility to "counter-rotate" the
 * mapping so that Cross is Red, Circle is Blue and so on.
 */
boolean useAlternativeCd32Mapping = false;

//! @}		// End of global variables

#ifdef ENABLE_SERIAL_DEBUG
	#include <avr/pgmspace.h>
	typedef const __FlashStringHelper * FlashStr;
	typedef const byte* PGM_BYTES_P;
	#define PSTR_TO_F(s) reinterpret_cast<const __FlashStringHelper *> (s)

	#define dstart(spd) Serial.begin (spd)
	#define debug(...) Serial.print (__VA_ARGS__)
	#define debugln(...) Serial.println (__VA_ARGS__)
#else
	#define dstart(...)
	#define debug(...)
	#define debugln(...)
#endif

/** \brief Initialize the Playstation controller
 * 
 * Note that this function takes a considerable amount of time.
 * 
 * \return True if a supported controller was found, false otherwise.
 */
boolean initPad () {
	boolean ret = false;

	// clock, command, attention, data, Pressures?, Rumble?
	if (psx.begin ()) {
		// Controller seems ready
		if (!psx.enterConfigMode ()) {
			/* We'll take this as good anyway, maybe it's an early controller
			 * that does not support any configuration, like the Namco Arcade
			 * Stick
			 */
			debugln (F("Cannot enter config mode"));
			ret = true;
		} else {
			switch (psx.getControllerType ()) {
			case PSCTRL_UNKNOWN:
				/* The Dual Shock controller gets recognized as this sometimes, or
				 * anyway, whatever controller it is, it might work
				 */
				debugln (F("Unknown Controller type found, using anyway"));
				ret = true;
				break;
			case PSCTRL_DUALSHOCK:
				debugln (F("DualShock Controller found"));
				ret = true;
				break;
			case PSCTRL_GUITHERO:
				/* We used to refuse this, as it does not look suitable, but then we
				 * found out that the Analog Controller (SCPH-1200) gets detected as
				 * this... :/
				 */
				debugln (F("Analog/GuitarHero Controller found"));
				ret = true;
				break;
			case PSCTRL_DSWIRELESS:
				debugln (F("Wireless Sony DualShock Controller found"));
				ret = true;
				break;
			}

			// Try to enable analog sticks
			if (!psx.enableAnalogSticks ()) {
				debugln (F("Cannot enable analog sticks"));
			}
							
			if (!psx.exitConfigMode ()) {
				debugln (F("Cannot exit config mode"));
			}
		}
	} else {
		debugln (F("No controller found"));
	}

	return ret;
}


/** \name Button name strings
 * 
 * These are only used for debugging and will not show up in the executable if
 * it is not enabled
 */
//! @{
const char buttonSelectName[] PROGMEM = "Select";
const char buttonL3Name[] PROGMEM = "L3";
const char buttonR3Name[] PROGMEM = "R3";
const char buttonStartName[] PROGMEM = "Start";
const char buttonUpName[] PROGMEM = "Up";
const char buttonRightName[] PROGMEM = "Right";
const char buttonDownName[] PROGMEM = "Down";
const char buttonLeftName[] PROGMEM = "Left";
const char buttonL2Name[] PROGMEM = "L2";
const char buttonR2Name[] PROGMEM = "R2";
const char buttonL1Name[] PROGMEM = "L1";
const char buttonR1Name[] PROGMEM = "R1";
const char buttonTriangleName[] PROGMEM = "Triangle";
const char buttonCircleName[] PROGMEM = "Circle";
const char buttonCrossName[] PROGMEM = "Cross";
const char buttonSquareName[] PROGMEM = "Square";

const char* const psxButtonNames[PSX_BUTTONS_NO] PROGMEM = {
	buttonSelectName,
	buttonL3Name,
	buttonR3Name,
	buttonStartName,
	buttonUpName,
	buttonRightName,
	buttonDownName,
	buttonLeftName,
	buttonL2Name,
	buttonR2Name,
	buttonL1Name,
	buttonR1Name,
	buttonTriangleName,
	buttonCircleName,
	buttonCrossName,
	buttonSquareName
};
//! @}

/** \brief Convert a button on the PSX controller to a small integer
 * 
 * Output will always be in the range [0, PSX_BUTTONS_NO - 1] and is not
 * guaranteed to be valid, so it should be checked to be < PSX_BUTTONS_NO before
 * use.
 * 
 * \param[in] psxButtons Button to be converted
 * \return A small integer corresponding to the "first" button pressed
 */
byte psxButtonToIndex (PsxButtons psxButtons) {
	byte i;

	for (i = 0; i < PSX_BUTTONS_NO; ++i) {
		if (psxButtons & 0x01) {
			break;
		}

		psxButtons >>= 1U;
	}

	return i;
}

#ifdef ENABLE_SERIAL_DEBUG
/** \brief Return the name of a PSX button
 * 
 * \param[in] psxButtons Button to be converted
 * \return A string (in flash) containing the name of the "first" buton pressed
 */
FlashStr getButtonName (PsxButtons psxButton) {
	FlashStr ret = F("");
	
	byte b = psxButtonToIndex (psxButton);
	if (b < PSX_BUTTONS_NO) {
		PGM_BYTES_P bName = reinterpret_cast<PGM_BYTES_P> (pgm_read_ptr (&(psxButtonNames[b])));
		ret = PSTR_TO_F (bName);
	}

	return ret;
}
#endif

/** \brief Print the names of all PSX buttons being pressed
 * 
 * \param[in] psxButtons Buttons to be printed
 */
void dumpButtons (PsxButtons psxButtons) {
#ifdef DEBUG_PAD
	static PsxButtons lastB = 0;

	if (psxButtons != lastB) {
		lastB = psxButtons;			// Save it before we alter it
		
		debug (F("Pressed: "));

		for (byte i = 0; i < PSX_BUTTONS_NO; ++i) {
			byte b = psxButtonToIndex (psxButtons);
			if (b < PSX_BUTTONS_NO) {
				PGM_BYTES_P bName = reinterpret_cast<PGM_BYTES_P> (pgm_read_ptr (&(psxButtonNames[b])));
				debug (PSTR_TO_F (bName));
			}

			psxButtons &= ~(1 << b);

			if (psxButtons != 0) {
				debug (F(", "));
			}
		}

		debugln ();
	}
#else
	(void) psxButtons;
#endif
}

/** \brief Disable the ISR servicing rising clock edges
 * 
 * This shall be called when CD32 mode is exited.
 */
inline void suspendClockInterrupt () {
	EIMSK &= ~(1 << INT1);
}

/** \brief Enable the ISR servicing rising clock edges
 * 
 * This shall be called when CD32 mode is entered.
 */
inline void restoreClockInterrupt () {
	EIFR |= (1 << INTF1);		// Clear any pending interrupts
	EIMSK |= (1 << INT1);
}

/** \brief ISR servicing edges on #PIN_PADMODE
 *
 * Called on PIN_PADMODE changing, this function shall set things up for CD32
 * mode, sample buttons and shift out the first bit on FALLING edges, and
 * restore Atari-style signals on RISING edges.
 */
#ifndef SUPER_OPTIMIZE
void onPadModeChange () {
#else
ISR (INT0_vect) {
#endif
#ifdef ENABLE_INSTRUMENTATION
	fastDigitalToggle (PIN_INTERRUPT_TIMING);
#endif
	if (fastDigitalRead (PIN_PADMODE) == LOW) {
		// Switch to CD32 mode

		// Immediately disable output on clock pin
		fastPinMode (PIN_BTNREGCLK, INPUT);
		
		// Output status of first button as soon as possible
		fastPinMode (PIN_BTNREGOUT, OUTPUT);
		if (!(*buttonsLive & 0x01)) {
			fastDigitalWrite (PIN_BTNREGOUT, LOW);
		} else {
			fastDigitalWrite (PIN_BTNREGOUT, HIGH);
		}
				
		/* Sample input values, they will be shifted out on subsequent clock
		 * inputs.
		 * 
		 * At this point MSB must be 1 for ID sequence. Then it will be zeroed
		 * by the shift. This will report non-existing buttons 8 as released and
		 * 9 as pressed as required by the ID sequence.
		 */
#ifndef SUPER_OPTIMIZE
		*isrButtons = *buttonsLive >> 1U;
#else
		asm volatile (
			"lsr %0\n\t"
			: "=r" (*isrButtons)
			: "r" (*buttonsLive)
		);
#endif
						 
		// Enable INT1, i.e. interrupt on clock edges
		restoreClockInterrupt ();

		// Set state to ST_CD32
#ifdef ENABLE_SERIAL_DEBUG
		if (*state != ST_CD32 && *state != ST_JOYSTICK_TEMP) {
			debugln (F("Joystick -> CD32"));
		}
#endif
		//~ stateEnteredTime = 0;		// Do this here too, we are unsure if the SM state is ever entered
		*state = ST_CD32;

#ifdef ENABLE_INSTRUMENTATION
		fastDigitalToggle (PIN_CD32MODE);
#endif
	} else {
		// Switch back to joystick mode

		/* Set pin directions and set levels according to buttons, as waiting
		 * for the main loop to do it takes too much time (= a few ms), for some
		 * reason
		 */
		/* PIN_BTN1 (aka PIN_BTNREGCLK) was an INPUT and it must either remain
		 * an input or become a low output, so this should be enough
		 */
		if (!(*buttonsLive & BTN_RED)) {
			buttonPress (PIN_BTN1);
		} else {
			buttonRelease (PIN_BTN1);
		}
		
		/* PIN_BTN2 (aka PIN_BTNREGOUT) was an output, either high or low, which
		 * means it might turn into a pulled-up input
		 */
		if (!(*buttonsLive & BTN_BLUE)) {
			// To LOW OUTPUT
			buttonPress (PIN_BTN2);
		} else {
			// To INPUT
			buttonRelease (PIN_BTN2);
		}
		fastDigitalWrite (PIN_BTN2, LOW);	/* Disable pull-up, don't do it before
											 * to avoid a spurious 0V state when
											 * going from output high to input
											 */
		
		// Disable INT1
		suspendClockInterrupt ();
			
		// Set state to ST_JOYSTICK_TEMP
		*state = ST_JOYSTICK_TEMP;
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
void loop () {
	stateMachine ();
	updateLeds ();

#ifdef ENABLE_DEBUG_LOOP_DURATION
	static unsigned long lastMillis = 0;
	
	unsigned long elapsed = millis () - lastMillis;
	debug (F("Elapsed ms = "));
	debugln (elapsed);
	lastMillis = millis ();
#endif
}

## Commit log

2019-06-30 Minor improvements
    [OpenPSX2AmigaPadAdapter.sch]
2019-06-30 Add cap for ATmega decoupling
    [OpenPSX2AmigaPadAdapter.sch]
2019-06-30 Port to KiCad 5
    [MyTrackr.sch, OpenPSX2AmigaPadAdapter.sch]
2019-06-30 Start work on PCB
2019-07-02 Begin working on PCB
    [OpenPSX2AmigaPadAdapter.kicad_pcb, OpenPSX2AmigaPadAdapter.sch]
2019-08-04 Ready for prototype
    [OpenPSX2AmigaPadAdapter.kicad_pcb]
2019-08-04 Add dimensions
    [OpenPSX2AmigaPadAdapter.kicad_pcb]
2019-09-10 Use pins as on PCB
2019-09-10 Fully implement button maps and general cleanup
2019-09-10 Avoid useless bit inversions
    [PS2_2_CD32.ino]
2019-09-10 Switch to... switch
2019-09-10 Remove register variable attempts These don't seem to be usable in Arduino
2019-09-10 Detach interrupt when switching back from CD32 mode
2019-09-11 Do not accelerate and brake at the same time
2019-09-11 Fix debug messages & do not crash when Amiga is reset
    [PS2_2_CD32.ino]
2019-09-11 Ready for V2 Added RESET button and lotsa minor adjustments
    [OpenPSX2AmigaPadAdapter.kicad_pcb, OpenPSX2AmigaPadAdapter.sch]
2019-09-11 Fix dimension
    [OpenPSX2AmigaPadAdapter.kicad_pcb]
2019-09-11 Use cross to brake when in Racing2, always set pin directions and some clean up
2019-09-12 Do not set pin directions twice
2019-09-12 Avoid sampling interrupt catching button value being filled in
    [PS2_2_CD32.ino]
2019-09-13 Add license
    [OpenPSX2AmigaPadAdapter.kicad_pcb, OpenPSX2AmigaPadAdapter.sch]
2019-09-13 Minor refinements
    [OpenPSX2AmigaPadAdapter.kicad_pcb]
2019-09-14 Override spurious switch to mouse mode on controller disonnection
2019-09-19 Move attachInterrupt() to wrapper function
2019-09-19 Use button names in debug messages and isolate led handling
2019-09-19 Rename led pin constant
2019-09-20 Add footprint for SMD resonator
    [OpenPSX2AmigaPadAdapter.kicad_pcb]
2019-09-20 Add pull-up resistors on DATA and ACK
    [OpenPSX2AmigaPadAdapter.kicad_pcb, OpenPSX2AmigaPadAdapter.sch]
2019-09-20 Cosmetic fixes
    [OpenPSX2AmigaPadAdapter.kicad_pcb]
2019-09-28 Allow disabling factory reset (Saves flash for ATmega88)
    [PS2_2_CD32.ino]
2019-10-01 Save some flash unifying button to index functions
2019-10-15 Add list of two-button games
2019-10-21 Switch back to joystick mode immediately after LOAD/SHIFT falling edge
2019-10-21 Remove pull-up on ACK. Add on B1/B2 outputs.
    [OpenPSX2AmigaPadAdapter.sch]
2019-10-21 Add capacitor on potx/y as per original CD32 controller
    [OpenPSX2AmigaPadAdapter.sch]
2019-10-21 Update PCB after changes to schematics
    [OpenPSX2AmigaPadAdapter.kicad_pcb]
2019-10-23 Output buttons sooner
2019-10-23 Update state diagram and pin mapping
2019-10-23 Update pin mapping
2019-10-23 Fix CD32 mode led
    [OpenPSX2AmigaPadAdapter.ino]
2019-10-25 Do not use {at,de}tachInterrupt() with SUPER_OPTIMIZE
2019-10-28 Avoid switching pin directions during CD32 mode
    [OpenPSX2AmigaPadAdapter.ino]
2019-10-28 Only poll controller every so often (Fixes mouse mode) Note that this required a lot of extra work.
    [OpenPSX2AmigaPadAdapter.ino]
2019-10-29 Ready for V2 PCB
    [OpenPSX2AmigaPadAdapter.kicad_pcb, OpenPSX2AmigaPadAdapter.sch]
2019-10-29 Do not switch from Mouse to CD32 mode
2019-10-30 Final PCB fixes for V2
    [OpenPSX2AmigaPadAdapter.kicad_pcb, OpenPSX2AmigaPadAdapter.sch]
2019-10-30 Add note about ArduinoISP
2019-10-30 Remove unused factory reset code
    [OpenPSX2AmigaPadAdapter.ino]
2019-10-30 Add C64-style 2nd button. Closes #4.
2019-11-03 Init joystick mode correctly after factory reset This is important because some (knockoff) controllers seem to report SELECT pressed at start. This made us start in factory reset mode for a moment, a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
    [OpenPSX2AmigaPadAdapter.ino]
2019-11-08 Add renders
    [OpenPSX2AmigaPadAdapter.kicad_pcb]
2019-11-09 Correct PCBway project link
2019-11-09 Add 3D model of PSX connector
    [OpenPSX2AmigaPadAdapter.kicad_pcb, pritesh.igs, pritesh.stp]
2019-11-09 Add command for setting fuses of ATmega328PB
2019-11-09 Buttons -> PsxButtons
2019-12-10 Use handsoldering footprints and fix FTDI connector
    [OpenPSX2AmigaPadAdapter.kicad_pcb, OpenPSX2AmigaPadAdapter.sch]
2020-01-02 Connect ACK signal and remove RESET button
    [OpenPSX2AmigaPadAdapter.kicad_pcb, OpenPSX2AmigaPadAdapter.sch]
2020-01-02 Fix component naming
    [OpenPSX2AmigaPadAdapter.kicad_pcb, OpenPSX2AmigaPadAdapter.sch]
2020-01-02 Add schematics
2020-02-19 Add Fusion 360 project of 3D-Printable enclosure
2020-03-26 Fix for latest changes in PsxNewLib
    [OpenPSX2AmigaPadAdapter.ino]
2020-03-26 Add alternative CD32 button mapping
2020-03-26 Add info about the alternate CD32 button mapping
2020-03-26 Update renders and board link
2020-10-02 added enclosure for cd32
    [OpenPSXAdapter-LowerShell-cd32.skp, OpenPSXAdapter-LowerShell-cd32.stl, OpenPSXAdapter-UpperShell-cd32.skp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]
2020-10-04 cleaned up and added no leg version
    [OpenPSXAdapter-LowerShell-cd32.skp, OpenPSXAdapter-LowerShell-cd32.stl, OpenPSXAdapter-LowerShell-no_leg-cd32.skp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]
2020-11-07 Add info about all enclosures currently available
2020-11-07 Add note about LED holes
2021-04-25 Clear selectComboButton when it's no longer needed
    [OpenPSX2AmigaPadAdapter.ino]

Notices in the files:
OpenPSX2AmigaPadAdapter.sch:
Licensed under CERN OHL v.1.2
